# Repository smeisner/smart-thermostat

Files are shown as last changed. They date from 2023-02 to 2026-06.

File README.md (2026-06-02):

# Smart Thermostat

The idea of this project is to create a truly smart thermostat.
Main features are:

* Can be integrated into a home automation system (such as Home Assistant)
* Cloud connection not required
* WiFi connected
* Initial setup (e.g., WiFi credentials) configured via touch screen interface
* Will act similarly to a person's preferences when it comes to HVAC. For example:
    * the temperature set should be dependent upon local forecast
    * If the outside temp is close to the set thermostat temp, suggest opening a window
    * Detect if a window or door is open and disable the heat/AC
* Use Matter protocol over WiFi (thermostat V2)
* Provide local web site to control/configure thermostat
* Allow ssh login
* Provide diagnostic logging (rsyslog as well?)
* Detect degradation of temp rise/fall to identify clogged filter or service required
* Employ remote temp sensors to balance temp within home
* Detect lower air quality to suggest opening a window (and disable HVAC)
* No mechanical buttons - soft buttons on the TouchScreen only ... except maybe a master reset if things go wrong!

Basic layout of thermostat:

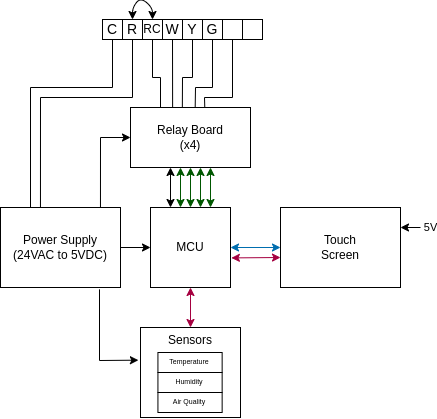
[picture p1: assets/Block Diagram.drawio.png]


# December 18, 2023 Changes to MQTT and addition of telnet support

Version 0.7.2 adds support for telnet and soft backlight bring up (more on that later). It also fixes a handful of bugs and reliability (especially around MQTT) has been dramatically increased.

Prior to this release, the backlight would come on immediately with "full brightness" (depending on the ambient light level). Now, the logic has been updated to bring the backlight up slowly to match the current room light level. Also the backlight will continue to match the detected light, so if you turn the room light on, it will match.

Auto reconnect in the ESP MQTT module has been enabled. This eliminates the responsibility for smart-thermostat to re-establish an MQTT connection if it is lost. Trying to do this manually led to race conditions and some incorrect logic assumptions. Now the built-in module (from Esspressif) handles it ... and it is incredibly reliable!

Telnet support has been added! There is no credential checking mechanism, but this is not a high security device. It could be added later by a contributor if wanted. Via telnet, a user can reconfigure the stat, monitoring the logging output, reboot and check on stats & error counts.

# October 4, 2023 addition of Matter support

Getting started: https://docs.espressif.com/projects/esp-matter/en/latest/esp32/developing.html

Matter support is delayed until the SDK can be added as a library to PlatformIO. Currently, the actions required to create a dev environment is too extreme.

# September 8, 2023 update - V0.6

The thermostat app code is now 100% ESP-IDF based. All dependencies on the Arduino framework have been removed. This provides for much better control of the code and better integration with the upcoming Matter implementation.

FYI: There are some libraries being used that have some compile-time errors. These are currently being worked with the maintainers. See PR comments.

FYI #2: Many details have changed with today's commit (such as the partition scheme). It is best to clear out old builds and be sure everything (ESP-IDF and libraries) are up-to-date. Details in the platformio.ini file.

# May 2023 update - V0.2

Great progress! The processor has been selected, the ESP-32 and the user interface is (albeit crude) created! To generate the user interface elements and menuing system, [SquareLine Studio](https://squareline.io/) was used. This integrates with the graphics library used; [LVGL](https://lvgl.io/).

## Operating environment

FreeRTOS will be the OS. Tasks are created to drive the user interface, the state machine, the web server and reading of the sensors. The state machine will make up the primary task that runs on a continuous, low-priority loop. The user interface task, which drives the TFT is the highest priority. All other tasks will have higher priorities.

The code is currently exceeding the usual partitioning table, so the large_app partition scheme was used. OTA update has not been tried since switching to this partition scheme, but it may now be broken. Later with an ESP32 chip with a larger FLASH should be able to handle the code and perform OTA updates.

## MCU

The processor of choice is the ESP32 with 4MB FLASH.

The choice to use an Espressif MCU was made since it is cheaper, smaller and more simple to integrate into the circuit. It also provides enough GPIO pins to control everything.

Eventually, the ESP32-C6 will be used as it has support for [802.15.4 (Zigbee / Thread)](https://en.wikipedia.org/wiki/IEEE_802.15.4). But it does not have enough GPIO pins, so a multiplexer must be added to the PCB. Alternatively, WiFi plus Matter could be used and skip Zigbee and Thread. This is still under investigation.

Built onto the PCB is a SWD interface allowing GDB debugging, as well as loading firmware. 

Currently, build output shows:

```
Processing esp32dev (platform: espressif32; board: esp32dev; framework: arduino)
---------------------------------------------------------------------------------------------------------------------------------------------------------------------------------
Verbose mode can be enabled via `-v, --verbose` option
CONFIGURATION: https://docs.platformio.org/page/boards/espressif32/esp32dev.html
PLATFORM: Espressif 32 (6.3.0) > Espressif ESP32 Dev Module
HARDWARE: ESP32 240MHz, 320KB RAM, 4MB Flash
DEBUG: Current (esp-prog) External (cmsis-dap, esp-bridge, esp-prog, iot-bus-jtag, jlink, minimodule, olimex-arm-usb-ocd, olimex-arm-usb-ocd-h, olimex-arm-usb-tiny-h, olimex-jtag-tiny, tumpa)
PACKAGES: 
 - framework-arduinoespressif32 @ 3.20009.0 (2.0.9) 
 - tool-esptoolpy @ 1.40501.0 (4.5.1) 
 - tool-mkfatfs @ 2.0.1 
 - tool-mklittlefs @ 1.203.210628 (2.3) 
 - tool-mkspiffs @ 2.230.0 (2.30) 
 - toolchain-xtensa-esp32 @ 8.4.0+2021r2-patch5
LDF: Library Dependency Finder -> https://bit.ly/configure-pio-ldf
LDF Modes: Finder ~ deep, Compatibility ~ soft
Found 42 compatible libraries
Scanning dependencies...
Dependency Graph
|-- LovyanGFX @ 1.1.6
|-- Adafruit AHTX0 @ 2.0.3
|-- Smoothed @ 1.2.0
|-- micro-timezonedb @ 1.0.2
|-- lvgl @ 8.3.7
|-- Preferences @ 2.0.0
|-- ESPmDNS @ 2.0.0
|-- Update @ 2.0.0
|-- WebServer @ 2.0.0
|-- WiFi @ 2.0.0
Building in release mode
Retrieving maximum program size .pio/build/esp32dev/firmware.elf
Checking size .pio/build/esp32dev/firmware.elf
Advanced Memory Usage is available via "PlatformIO Home > Project Inspect"
RAM:   [===       ]  33.1% (used 108372 bytes from 327680 bytes)
Flash: [=====     ]  45.9% (used 1445209 bytes from 3145728 bytes)
Configuring upload protocol...
AVAILABLE: cmsis-dap, esp-bridge, esp-prog, espota, esptool, iot-bus-jtag, jlink, minimodule, olimex-arm-usb-ocd, olimex-arm-usb-ocd-h, olimex-arm-usb-tiny-h, olimex-jtag-tiny, tumpa
CURRENT: upload_protocol = esptool
Looking for upload port...
Using manually specified: /dev/ttyUSB1
Uploading .pio/build/esp32dev/firmware.bin
esptool.py v4.5.1
Serial port /dev/ttyUSB1
Connecting.....
Chip is ESP32-D0WD-V3 (revision v3.0)
Features: WiFi, BT, Dual Core, 240MHz, VRef calibration in efuse, Coding Scheme None
Crystal is 40MHz
MAC: 78:21:84:e2:28:1c
Uploading stub...
Running stub...
Stub running...
Changing baud rate to 921600
Changed.
Configuring flash size...
Flash will be erased from 0x00001000 to 0x00005fff...
Flash will be erased from 0x00008000 to 0x00008fff...
Flash will be erased from 0x0000e000 to 0x0000ffff...
etc...
```

## Touch screen

The TFT display chosen is the [MSP3218](http://www.lcdwiki.com/3.2inch_SPI_Module_ILI9341_SKU:MSP3218) with the ILI9341 TFT driver and the XPT2046 touch controller. LVGL supports this display nicely (see lvgl_conf.h). The 3.2" screen is a bit tight for all menus and controls, but with a stylus, it is fine ... might be tough with a finger.

SquareLine Studio designed screens:<br>
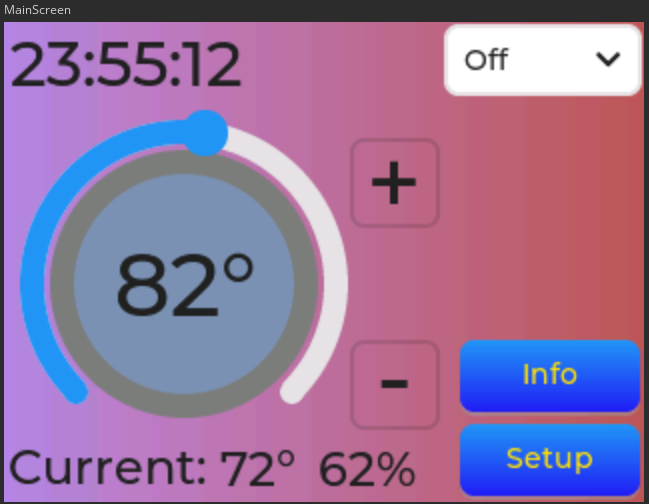
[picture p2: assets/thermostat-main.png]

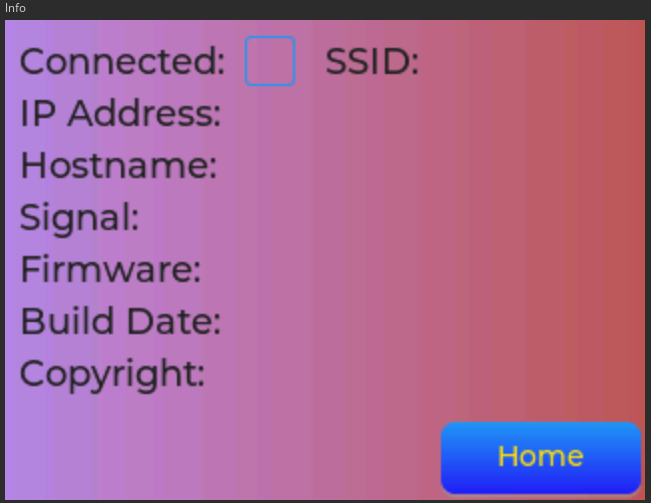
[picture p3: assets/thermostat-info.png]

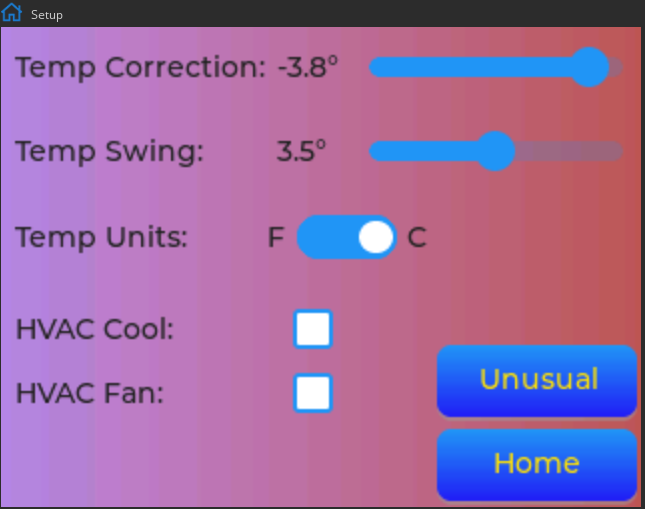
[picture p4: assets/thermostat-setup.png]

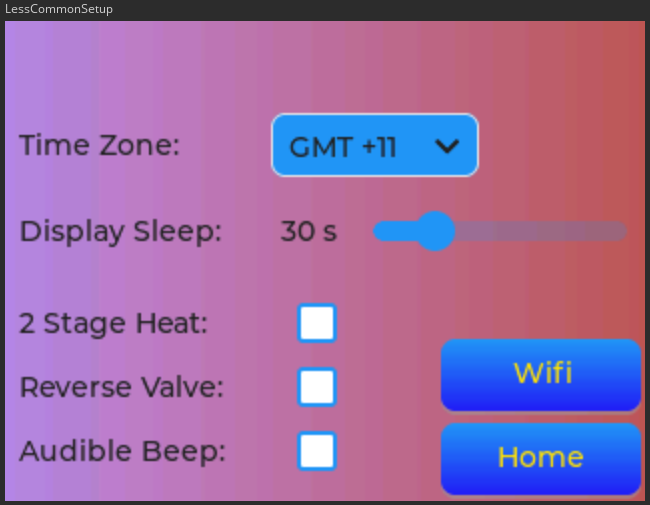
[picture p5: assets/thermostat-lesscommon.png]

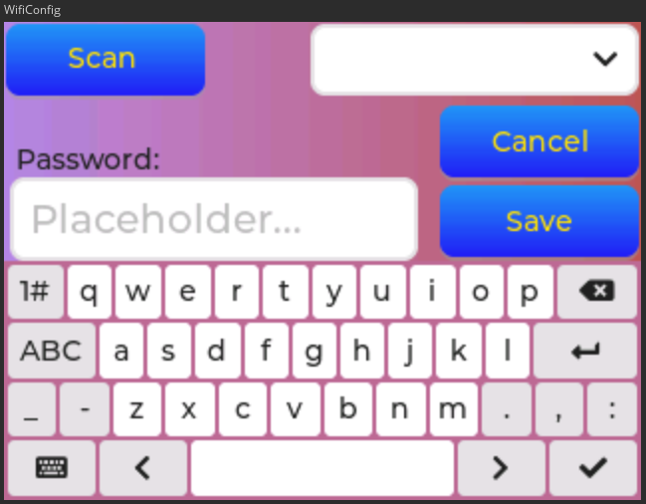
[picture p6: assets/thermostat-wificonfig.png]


## Power Supply

Built into the PCB is a power supply capable of providing stable 5V DC for the processor and sensors. An LM2576HVT-5 will be used to allow for 24V in and still remain stable regulating the power.

[LM2576HVT Datasheet](https://www.ti.com/general/docs/suppproductinfo.tsp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)

A low dropout voltage regulator is incorporated into the PCB to regulate the 5V to 3v3. [AMS1117 Datasheet](http://www.advanced-monolithic.com/pdf/ds1117.pdf)

## Sensors

Other than an onboard Temp/Humidity/Air quality sensor setup, there can also be remote sensors (maybe connected via MQTT or proprietary ethernet protocol?) that will provide data to make various decisions. These could be inside the home, outside or even from online sources (such as local weather sites).

To measure indoor temp & humidity, the [Aosong AHT20](http://www.aosong.com/userfiles/files/media/Data%20Sheet%20AHT20.pdf) is being used. More manufacturer information can be found [HERE](http://www.aosong.com/en/products-32.html).

A light sensor (LDR) is currently incoporated into the PCB (as a voltage divider) and is being measured for ambient light. It will be used to determine brightness of the TFT display when it is woken.

Motion sensing is being done with the Hi-Link LD2410 uWave sensor. These are available on [Amazon](https://www.amazon.com/Microwave-Radar-Sensor-Module-LD2410-24GHz-ISM-Band-Human-Presence-Motion-Sensing-Module-Non-Contact-Monitoring-Detector-Support-GPIO/dp/B0BP6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) and [AliExpress](https://m.aliexpress.com/item/1005004351593073.html).

* LD2410 documentation: https://drive.google.com/drive/folders/1p4dhbEJA3YubyIjIIC7wwVsSo8x29Fq-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
* Example use in another poject: https://github.com/LoopOnCode/UnitySensor
* You can purchase a Unity Sensor at: https://loopon.tech/products/unity-sensor

## Possibilities

#### Integrate SMS/chat ability

This can be used to notify user of events/alerts. Could also be Slack or other notifications. An onboard annunciator (like a speaker) feels wrong.

#### Use super capacitor to maintain power during power outage

This would maintain power during brief power outages

***

V1 task list:

* [x] Build 24VAC to 5VDC power supply with minimal ripple (< 2%)
* [x] Decide on MCU/SBC
* [x] Determine sensors to be used (temp, humidity, air quality)
* [x] Develop V1 of host app (to get basic thermostat functionality)
* [x] Generate schematic & PCB
* [x] Generate PCB BOM (compatible with JLCPCB parts list)
* [x] Have PCB manufactured (JLCPCB)
* [x] Add OTA update ability (via web page)

V2 task list:

* [x] Design device web page; crude but done
* [x] Design 3D printed case (Polycase may be good supplier or JLCPCB)
* [ ] Implement Matter
* [ ] Develop Home Assistant integration (maybe via Matter?)
* [x] Add MQTT/HA communications (publish and subscriber support)

Maybe:

* [ ] Add air quality monitoring (to PCB and app)

General to-do:

* [ ] Measure current draw of entire thermostat, TFT LED backlight on & off
* [ ] Measure current draw with no TFT display attached
* [ ] Measure voltage ripple while under load
* [x] Redesign PCB to incoporate ESP chip and tighten up layout
* [x] Add serial output pins to connect serial terminal to catch print statements

## Specs...
 
#### FreeRTOS Elements:
 
* Interrupt: Touch
* When: User touches display; Asserts line LO
<br>

* Interrupt: Motion
* When: LD2410 senses motion; asserts line HI
<br>

* Task: aht
* Freq: 10 secs
* Purpose: update temp & humidity
<br/>

* Task: touch
* Freq: int (triggered indirectly via TFT touch int)
* Purpose:
  - Update last touch point
  - Play audible beep
<br>

* Task: motion
* Freq: int (triggered directly via motion int)
* Purpose: update last motion detected timestamp
<br/>

* Task: state-machine
* Freq: 1 sec
* Purpose:
  - Pump state machine
  - Using temp & humidity, motion, last touch pt,
  - Call routines to navigate menus (options / settings)
  - Adjust display brightness (when on) based on LDR
  - Turn off display with no motion

#### States:

* Init (start)
* Idle
* Fan only
* Heat
* Cool
* Error

#### To be added:

* [x] WiFi
* [x] Web server
* [ ] Matter over WiFi
* [x] Telnet
* [x] OTA updates
* [ ] Add air quality monitoring device -- Maybe a future feature

#### Parameters set by user:

* WiFi credentials
* Location (zip code) for outdoor temp - or URI for local/private temp sensor
* Home Assistant FQDN / IP
* Temp swing
* Max / min temp (when to alert user)
* email list / SMS for notifications
* c / f
* reversing valve (for a heat pump)
* auto changeover (A/C to/from Heat)

#### Calculated params:

* Average temp change rate vs temp differential (inside / outside temps)
    * When value exceeded (based on HVAC mode), ask if window/door is open
* Average temp change rate
    * Detects when filter / furnace needs servicing
    * Used to calculate time to temp

#### Analyze core dump core:

Be sure ESP tools are installed:
```~/.platformio/packages/framework-espidf/install.sh```
<br><br>
Then run export:
```source ~/.platformio/packages/framework-espidf/export.sh```
<br><br>
Then run the ```esp-coredump``` utility to analyze a core dump file. It will be stored on the SD card in the event of a crash.
<br><br>
* Example;
  ```esp-coredump info_corefile --rom-elf ~/.espressif/tools/esp-rom-elfs/20241011/esp32s3_rev0_rom.elf -c ~/COREDUMP.BIN ~/projects/smart-thermostat/app/.pio/build/esp32s3/firmware.elf```
<br><br>
Another possible location for chip ELF files:
```~/.platformio/tools/tool-esp-rom-elfs/```

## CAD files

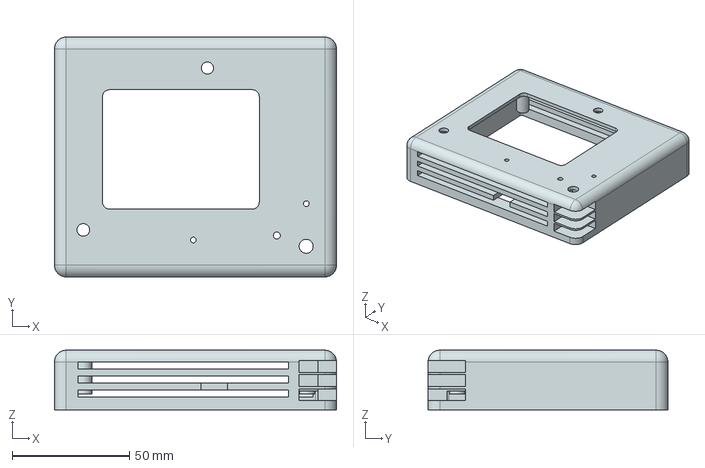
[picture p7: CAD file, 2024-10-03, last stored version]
pcb/3d/thermo-housing-front.stp
120.5 x 102.5 x 25.5 mm

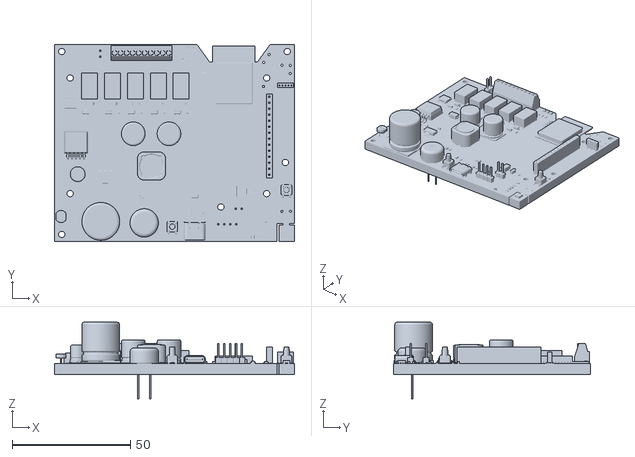
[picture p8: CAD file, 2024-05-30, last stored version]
pcb/FabConvert.com_thermostat v0.6.0.stl
101.5 x 83.4 x 32.5

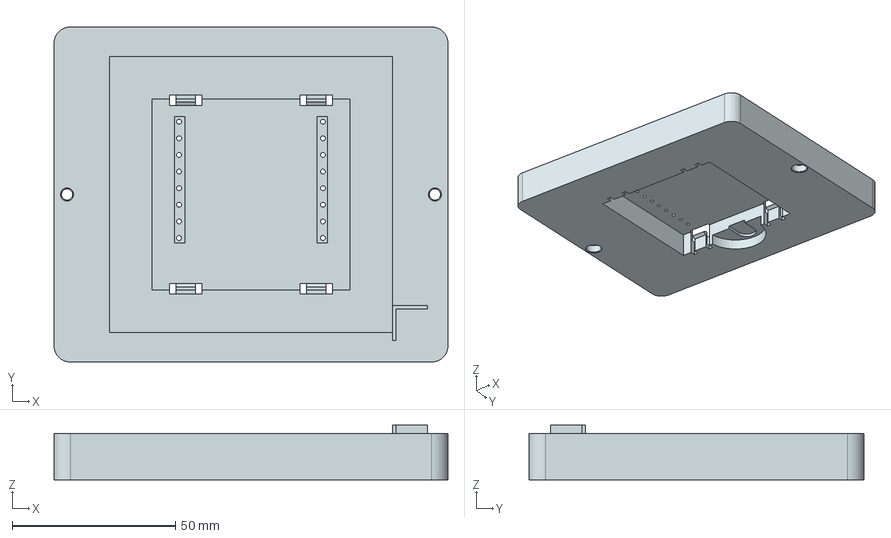
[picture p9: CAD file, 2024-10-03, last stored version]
pcb/3d/thermo-housing-back.stp
120.5 x 102.5 x 16.7 mm

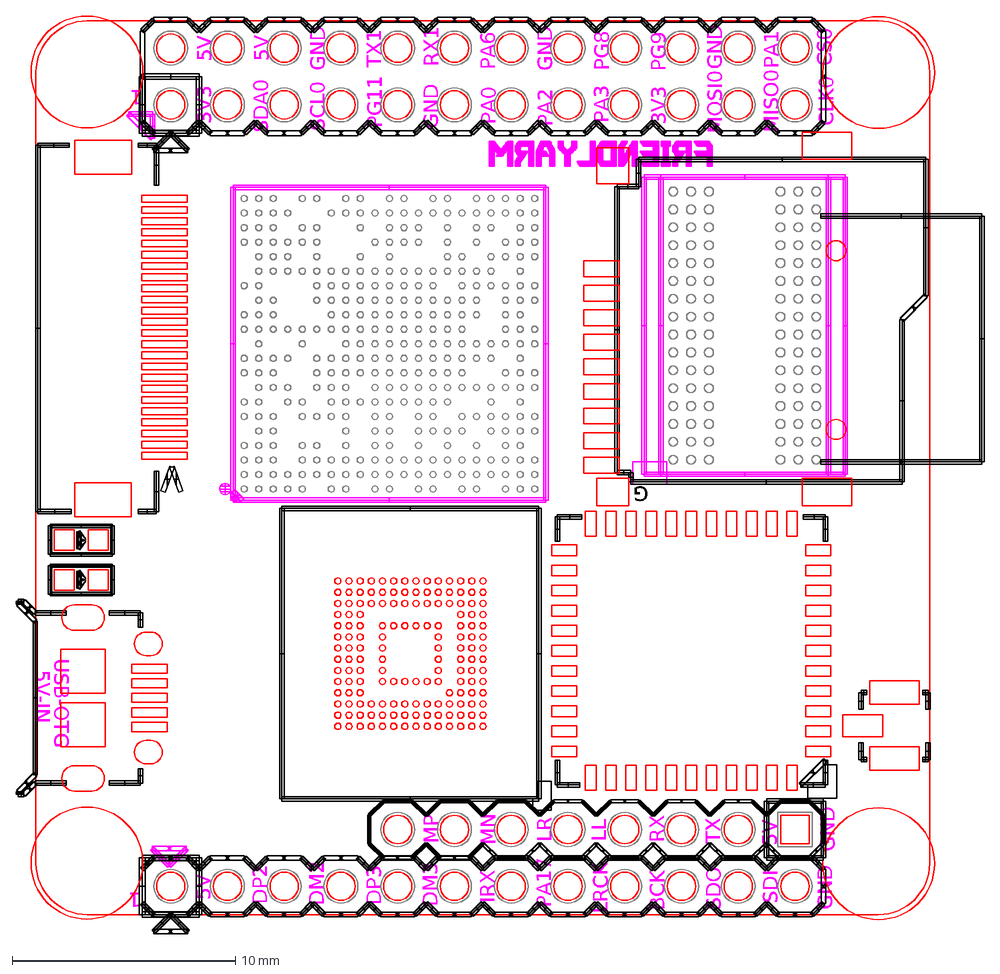
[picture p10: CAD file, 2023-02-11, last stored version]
pcb/NanoPi_NEO_Air-V1.1-1708.dxf
CS0
PA1
GND
PG9
PG8
PA6
RX1
TX1
5V
CLK0
MISO0
MOSI0
3V3
PA3
PA2
PA0
PG11
SCL0
SDA0
RX
LR
LL
TX
SDI
SDO
BCK
LRCK
PA17
MN
IRX
MP
DM3
DP3
DM2
DP2
USB-OTG
5V-IN
1
G

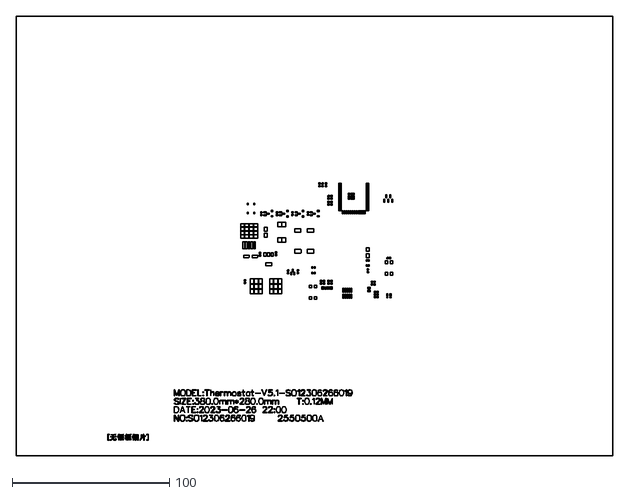
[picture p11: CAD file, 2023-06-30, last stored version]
pcb/stencil-v.0.5.1/SO12306266019.dxf
380.0 x 280.0

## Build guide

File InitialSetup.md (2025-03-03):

Upon first power up, follow these directions to setup wifi, set the device name and connect to MQTT:

First set up WIFI:
  1. From main screen, tap SETUP
  2. Tap the MORE button
  3. Then tap WIFI
  4. And finally perform a scan. After the scan completes, configure the SSID and password.
  5. Upon tapping SAVE, the thermostat should restart.

After the WIFI is connected (designated by Blue wifi icon on the home screen), perform the following:
  1. Tap SETUP
  2. MORE
  3. NAME
  4. In the text box, enter the Friendly Name to be used by Home Assistant. This name can include spaces.
  5. Tap SAVE
 
Now set up the MQTT connection:
  1. Tap SETUP
  2. MQTT
  3. Configure MQTT settings including broker, username and passowrd. Note: Port 1883 is assumed.

Once you return to the main screeen, go back into setup:
  1. Tap SETUP
  2. Check the box next to MQTT Enable
  3. Tap SAVE

NOTE: Using the telnet console, you can use the `config` command to go thru all of the configuration parameters, including setting the MQTT port. So it can be changed using this method.

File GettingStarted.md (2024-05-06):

# Getting Started

> [!NOTE]
> These steps are not fully verified or validated on every release yet or Linux distribution. Please add any modifications to them as needed.
>
> The instructions here preseted were tested on Debian 11 (Bullseye) and 12 (Bookworm), and Fedora 39.

## Release Notes

* NB #1: The v0.5.2 prototype boards have an odd connectivity issue with the USB ports. If you see 'oddness', flip the cable around and try that. It should work since all prototypes are tested before leaving my workbench.

* NB #2: There was an error on the v0.5.2 proto; the top right corner has 3 test points; GND, 5V and 3V3. I misconfigured the net connection for the 3v3 and it ended up not being connected. So don't use it to test...it's not connected.

* NB #3: If the board has been powered off for a bit, it starts up in boot mode when power is applied. Therefore, the reset button must be pushed. I am guessing this is a power-up problem...if anyone can suggest a PCB change, I will include it in the next run!

## Steps to build environment:

### Of course, update the system first:

<details>
<summary>Debian</summary>

`sudo apt update --allow-releaseinfo-change && sudo apt upgrade`
</details>

<details>
<summary>Fedora</summary>

`sudo dnf upgrade --refresh`
</details>

### Install the prerequisite packages

<details>
<summary>Debian</summary>

`sudo apt install git curl wget python3-pip python3-venv apt-transport-https gpg`
</details>

<details>
<summary>Fedora</summary>

On Fedora, python3 already bundles venv module by default<br>
`sudo dnf install git curl wget python3-pip gnupg`
</details>

### Build the dev environment:

#### Install Visual Studio Code

The following info was mostly got from https://code.visualstudio.com/docs/setup/linux

<details>
<summary>Debian</summary>

```
$ wget -qO- https://packages.microsoft.com/keys/microsoft.asc | gpg --dearmor > packages.microsoft.gpg
$ sudo install -D -o root -g root -m 644 packages.microsoft.gpg /etc/apt/keyrings/packages.microsoft.gpg
$ sudo sh -c 'echo "deb [arch=amd64,arm64,armhf signed-by=/etc/apt/keyrings/packages.microsoft.gpg] https://packages.microsoft.com/repos/code stable main" > /etc/apt/sources.list.d/vscode.list'
$ rm -f packages.microsoft.gpg
```

Add the VS Code repository to the cache:

`sudo apt update`

The above will add the repository key locally. Next we need to install the VS Code package itself:

`sudo apt install code`
</details>

<details>
<summary>Fedora</summary>

```
$ sudo rpm --import https://packages.microsoft.com/keys/microsoft.asc
$ echo -e "[code]\nname=Visual Studio Code\nbaseurl=https://packages.microsoft.com/yumrepos/vscode\nenabled=1\ngpgcheck=1\ngpgkey=https://packages.microsoft.com/keys/microsoft.asc" | sudo tee /etc/yum.repos.d/vscode.repo > /dev/null
```

Add the VS Code repository to the cache:

`sudo dnf update`

The above will add the repository key locally. Next we need to install the VS Code package itself:

`sudo dnf install code`
</details>

#### Install PlatformIO:<br>

```
$ curl -fsSL -o get-platformio.py https://raw.githubusercontent.com/platformio/platformio-core-installer/master/get-platformio.py`
$ python3 get-platformio.py
```

Add PlatformIO tools to the path:<br>

`echo "export PATH=\$PATH:/home/$USER/.platformio/penv/bin" >> ~/.profile`

#### Install udev rules

This will allow for recognizing the ESP32 USB JTAG device correctly.<br>
Source: [PlatformIO doc for 99-platformio-udev.rules](https://docs.platformio.org/en/stable/core/installation/udev-rules.html)

```
$ curl -fsSL https://raw.githubusercontent.com/platformio/platformio-core/develop/platformio/assets/system/99-platformio-udev.rules | sudo tee /etc/udev/rules.d/99-platformio-udev.rules
$ sudo udevadm control --reload-rules
```

Add user to the proper groups:

```
$ sudo usermod -a -G dialout $USER
$ sudo groupadd plugdev
$ sudo usermod -a -G plugdev $USER
```

NB: You must logout and back in again for this to take effect!! Otherwise, you will fail to write firmware images to the device.

#### Clone the thermostat repo

`git clone https://github.com/smeisner/smart-thermostat`

In the cloned repo, go into the 'app' folder and open the VS Code workspace smart-thermostat.code-workspace. With the included `platformio.ini` and the board definition files, you should be able to compile and flash to an ESP32-S3:

```
code smart-thermostat.code-workspace
```

If the above fails to launch VSCode, go to the system menu and select Visual Studio Code under Development. Then File, Open Workspace from File and navigate to the `smart-thermostat.code-workspace` file in the `app` folder.

In VS Code install the PlatformIO IDE extension (you should be prompted to add it). This will lead to installing many packages the first time. Any package needed by PlatformIO and the project will be installed. Once you see `Project has been successfully updated!`, all extra packages have been installed.

> [!CAUTION]
> A problem with ESP SDK/IDF has been discovered, causing build problems.
>
> In the file `esp_idf_version.h`, at `~/.platformio/packages/framework-espidf/components/esp_common/include/`, redefine the following macros, at the top of the module, to the values:
>
> ```c
> /** Major version number (X.x.x) */
> #define ESP_IDF_VERSION_MAJOR 6
> /** Minor version number (x.X.x) */
> #define ESP_IDF_VERSION_MINOR 6
> /** Patch version number (x.x.X) */
> #define ESP_IDF_VERSION_PATCH 0
> ```
>
> The default setup has the wrong IDF version (5.2.1), causing a number of yellow-colored warnings during build phase and a final build failure.
>
> Most of the warnings are: `warning: compound assignment with 'volatile'-qualified left operand is deprecated`
> that exist in the graphics library. They are warnings that can be ignored for now, **but they have been reported and hopefully addressed soon**.

Finally, plug in an ESP32-S3 based thermostat and try a build and flash the firmware via VSCode / PlatformIO!!

## Hints for setup & install

* Set up git properly to do pulls & commits
```
$ git config --global user.name "John Doe"
$ git config --global user.email johndoe@example.com
```
* Be sure sym link for python invokes python3 (I am using 3.9). Check "`which python`".

Notes:
a. Any PSRAM will be disabled. This is due to a pin conflicts on the MCU.
b. At least 8MB is required on the ESP32-S3 SOC. Adjust the `board\_build.partitions` in the `platformio.ini` as necessary.

### Components / Libraries used

***

**LovyanGFX** - Graphics driver for the MSP3218 TFT display and touch screen<br>
**lvgl** - Menuing system layered on top of LovyanGFX to generate screens and menus<br>
**micro-timezonedb** - Timezone database support to configure any timezone setting<br>
**Smoothed** - Automatically average values over a sample period<br>
**DFRobot_AHT20** - Class library to support the AHT20 sensor (much simpler and reliable than Adafruit's)<br>
**SquareLine Studio** - Design and develop the lvgl menuing system & screens.

### Debugging / flashing

***

The board includes a SWD port, but so far using the built in USB controller in the S3 has worked fine. This is also true for flashing new code over the USB port. The device will show up on the USB bus usually as `/dev/ttyACM0` which is the JTAG interface of the ESP32.

The following was removed. Leaving here as it may be reimplemented at some point:
```
There is also a 4 pin UART port on the board. This is used for serial comms. All serial.print statements end up here, as well as system debug information. In the state machine loop, the USB port is checked for input (as in the user typing on the serial console). Only a few commands are supported right now:
reset
scan
temp
The method implemented is very crude, so be careful!

`/dev/ttyUSBx` is the UART
`/dev/ttyACMx` is the ESP32
```

### Learning the source code

***

Start with the `main.cpp` file to understand the flow of the code. It is using FreeRTOS...but OS functions are used modestly, so it may not be obvious quickly. The `state_machine.cpp` module is the main loop of the thermostat (makes HVAC decisions and network retries). Other modules are fairly obvious.

Each module does have a brief description in the header.

`matter.cpp` is not yet being compiled as the SDK is not part of the environment yet.

### Resources/Links:

***

Install VS Code

* Download .deb file
    `wget https://code.visualstudio.com/sha/download?build=stable&os=linux-deb-x64`
    `sudo apt install ./code_1.79.0-1686149120_amd64.deb`

Install PlatformIO

* [https://platformio.org/install](https://platformio.org/install)
* Install as an extension inside Visual Studio Code
* Currently installed: PlatformIO IDE v3.2.0

Access Thermostat web interface

* [http://thermostat.local/](http://thermostat.local/)

ESP32 Arduino Matter port

* [https://github.com/Yacubane/esp32-arduino-matter](https://github.com/Yacubane/esp32-arduino-matter)
* [Announcement] [https://www.reddit.com/r/esp32/comments/yfq5sy/i_have_created_matter_library_for_esp32_running/](https://www.reddit.com/r/esp32/comments/yfq5sy/i_have_created_matter_library_for_esp32_running/)
* Download zip: `https://github.com/Yacubane/esp32-arduino-matter/releases/download/v1.0.0-beta.5/esp32-arduino-matter.zip`
    `cd smart-thermostat/app/lib`
    `gunzip "~/esp32-arduino-matter.zip"`

SquareLine Studio

* [https://squareline.io/](https://squareline.io/)

DFRobot AHT20 library

* [https://github.com/DFRobot/DFRobot_AHT20](https://github.com/DFRobot/DFRobot_AHT20)

LD2410 uWave Human Presence sensor

* [https://github.com/ncmreynolds/ld2410](https://github.com/ncmreynolds/ld2410)

PlatformIO documentation

* [https://docs.platformio.org/en/stable/what-is-platformio.html](https://docs.platformio.org/en/stable/what-is-platformio.html)

NTP Support library

* [https://mischianti.org/2020/08/08/network-time-protocol-ntp-timezone-and-daylight-saving-time-dst-with-esp8266-esp32-or-arduino/](https://mischianti.org/2020/08/08/network-time-protocol-ntp-timezone-and-daylight-saving-time-dst-with-esp8266-esp32-or-arduino/)

Arduino ESP32 doc

* [https://docs.espressif.com/\_/downloads/arduino-esp32/en/latest/pdf/](https://docs.espressif.com/_/downloads/arduino-esp32/en/latest/pdf/)

#### FreeRTOS

***

FreeRTOS and Task Priorities

* [https://www.freertos.org/RTOS-task-priority.html](https://www.freertos.org/RTOS-task-priority.html)

Amazon FreeRTOS User Guide

* [https://thingspace.verizon.com/content/dam/thingspace-portal/files/pdf/CloudConectors_Amazon_freertos-ug.pdf](https://thingspace.verizon.com/content/dam/thingspace-portal/files/pdf/CloudConectors_Amazon_freertos-ug.pdf)

Multitasking on ESP32 with Arduino and FreeRTOS

* [https://savjee.be/blog/multitasking-esp32-arduino-freertos/](https://savjee.be/blog/multitasking-esp32-arduino-freertos/)

Implement Freertos With Arduino Ide On Esp32

* [https://www.electromaker.io/project/view/implement-freertos-with-arduino-ide-on-esp32-1](https://www.electromaker.io/project/view/implement-freertos-with-arduino-ide-on-esp32-1)

ESP32 Interrupts and Timers with PIR Sensor using Arduino IDE

* [https://microcontrollerslab.com/esp32-interrupts-timers-pir-sensor-arduino-ide/](https://microcontrollerslab.com/esp32-interrupts-timers-pir-sensor-arduino-ide/)

#### Misc Hardware Info

***

ESP32 Espressif Hardware page

* [https://www.espressif.com/en/products/modules](https://www.espressif.com/en/products/modules)
* [https://www.espressif.com/en/products/socs/esp32-s3](https://www.espressif.com/en/products/socs/esp32-s3)

ESP32 device with thread (matter) support?

* [https://www.reddit.com/r/esp32/comments/1079h3a/esp32_device_with_thread_matter_support/](https://www.reddit.com/r/esp32/comments/1079h3a/esp32_device_with_thread_matter_support/)

Wifi management tricks

* [https://randomnerdtutorials.com/esp32-useful-wi-fi-functions-arduino/](https://randomnerdtutorials.com/esp32-useful-wi-fi-functions-arduino/)

Wifi connect using lvgl

* [https://github.com/xpress-embedo/ESP32/blob/master/ConnectToWiFi/src/main.cpp](https://github.com/xpress-embedo/ESP32/blob/master/ConnectToWiFi/src/main.cpp)
* [https://www.youtube.com/watch?v=X-Xv36ZO460](https://www.youtube.com/watch?v=X-Xv36ZO460)
* [https://github.com/pjaos/mgos_esp32_littlevgl_wifi_setup/blob/master/src/setup_wifi/setup_wifi_gui.c](https://github.com/pjaos/mgos_esp32_littlevgl_wifi_setup/blob/master/src/setup_wifi/setup_wifi_gui.c)

Article on PSRAM

* [https://thingpulse.com/esp32-how-to-use-psram/](https://thingpulse.com/esp32-how-to-use-psram/)

Touchscreen Controller (XPT2046)

* [https://github.com/PaulStoffregen/XPT2046_Touchscreen](https://github.com/PaulStoffregen/XPT2046_Touchscreen)

Switching Regulator Noise Reduction with an LC Filter

* [https://www.analog.com/media/en/technical-documentation/tech-articles/switching-regulator-noise-reduction-with-an-lc-filter.pdf](https://www.analog.com/media/en/technical-documentation/tech-articles/switching-regulator-noise-reduction-with-an-lc-filter.pdf)

I2C Scanner

* [https://learn.adafruit.com/adafruit-esp32-s3-feather/i2c-scan-test](https://learn.adafruit.com/adafruit-esp32-s3-feather/i2c-scan-test)

RCWL-0516 Range (Historical as this sensor is no longer planned for fab)

* [https://github.com/jdesbonnet/RCWL-0516/issues/11#issuecomment-771810294](https://github.com/jdesbonnet/RCWL-0516/issues/11#issuecomment-771810294)
* [https://github.com/jdesbonnet/RCWL-0516/issues/22](https://github.com/jdesbonnet/RCWL-0516/issues/22)

#### ESP32-S3 reference designs

***

* [https://learn.adafruit.com/assets/110822](https://learn.adafruit.com/assets/110822)
* [https://easyeda.com/editor#id=d056f47be7564dccbc8593766bcbeab5](https://easyeda.com/editor#id=d056f47be7564dccbc8593766bcbeab5)
* [https://easyeda.com/editor#id=4c9a270201564f79a8d898b16cb32a4a|030d87584b3241f4acb42f6090e3f78e|ad3bd37529b84bd0b1b817e14244c56d|10bc426910154bc18a781dce0e926303|ff30c5c9faf3437b93b7cbbef5ea03e9](https://easyeda.com/editor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)
* [https://oshwlab.com/thecharge/esp-32-s3-wroom-1-board-redesign](https://oshwlab.com/thecharge/esp-32-s3-wroom-1-board-redesign)
* [https://www.reddit.com/r/PrintedCircuitBoard/comments/110phjq/repostpcb_review_an_iot_playground_board_based_on/](https://www.reddit.com/r/PrintedCircuitBoard/comments/110phjq/repostpcb_review_an_iot_playground_board_based_on/)

#### USB Port sourcing (for PCB fab)

***

* [https://www.lcsc.com/product-detail/USB-Connectors_G-Switch-GT-USB-7010ASV_C2988369.html](https://www.lcsc.com/product-detail/USB-Connectors_G-Switch-GT-USB-7010ASV_C2988369.html)
* [https://www.jae.com/en/topics/detail/id=92529](https://www.jae.com/en/topics/detail/id=92529)
* [https://www.mouser.com/ProductDetail/JAE-Electronics/DX07S016JA1R1500?qs=GBLSl2Akirucb2YMMGCxCQ%3D%3D](https://www.mouser.com/ProductDetail/JAE-Electronics/DX07S016JA1R1500?qs=GBLSl2Akirucb2YMMGCxCQ%3D%3D)

#### Google Sheets

***

* Sheet to determine GPIO pin usage
   * [https://docs.google.com/spreadsheets/d/10CfVb4AoQPJP5FjagokVNWyHDSV7czo9InDzF5tszXg/edit#gid=0](https://docs.google.com/spreadsheets/d/10CfVb4AoQPJP5FjagokVNWyHDSV7czo9InDzF5tszXg/edit#gid=0)
* BOM Analysis
   * [https://docs.google.com/spreadsheets/d/14w7VYzvXJafxjo8qtsvuFqKP_Zvz_vr7KMgLZYts2Cs/edit?pli=1#gid=310427562](https://docs.google.com/spreadsheets/d/14w7VYzvXJafxjo8qtsvuFqKP_Zvz_vr7KMgLZYts2Cs/edit?pli=1#gid=310427562)

## Sample output from build (using ProxMox, passing thru the ESP32 USB device)
```
*  Executing task in folder SmartThermostat: platformio run --target upload 

Processing esp32dev (platform: espressif32; board: esp32-s3-thermostat; framework: arduino)
----------------------------------------------------------------------------------------------------------------
Tool Manager: Installing platformio/tool-mkspiffs @ ~2.230.0
Downloading  [####################################]  100%
Unpacking  [####################################]  100%
Tool Manager: tool-mkspiffs@2.230.0 has been installed!
Tool Manager: Installing platformio/tool-mklittlefs @ ~1.203.0
Downloading  [####################################]  100%
Unpacking  [####################################]  100%
Tool Manager: tool-mklittlefs@1.203.210628 has been installed!
Tool Manager: Installing platformio/tool-mkfatfs @ ~2.0.0
Downloading  [####################################]  100%
Unpacking  [####################################]  100%
Tool Manager: tool-mkfatfs@2.0.1 has been installed!
Verbose mode can be enabled via `-v, --verbose` option
CONFIGURATION: https://docs.platformio.org/page/boards/espressif32/esp32-s3-thermostat.html
PLATFORM: Espressif 32 (6.2.0) > Espressif ESP32-S3-Thermostat (16 MB QD, No PSRAM)
HARDWARE: ESP32S3 240MHz, 320KB RAM, 16MB Flash
DEBUG: Current (esp-builtin) On-board (esp-builtin) External (cmsis-dap, esp-bridge, esp-prog, iot-bus-jtag, jlink, minimodule, olimex-arm-usb-ocd, olimex-arm-usb-ocd-h, olimex-arm-usb-tiny-h, olimex-jtag-tiny, tumpa)
PACKAGES: 
 - framework-arduinoespressif32 @ 3.20008.0 (2.0.8) 
 - tool-esptoolpy @ 1.40501.0 (4.5.1) 
 - tool-mkfatfs @ 2.0.1 
 - tool-mklittlefs @ 1.203.210628 (2.3) 
 - tool-mkspiffs @ 2.230.0 (2.30) 
 - toolchain-riscv32-esp @ 8.4.0+2021r2-patch5 
 - toolchain-xtensa-esp32s3 @ 8.4.0+2021r2-patch5
LDF: Library Dependency Finder -> https://bit.ly/configure-pio-ldf
LDF Modes: Finder ~ deep, Compatibility ~ soft
Found 37 compatible libraries
Scanning dependencies...
Dependency Graph
|-- LovyanGFX @ 1.1.7
|-- Smoothed @ 1.2.0
|-- micro-timezonedb @ 1.0.2
|-- lvgl @ 8.3.7
|-- Wire @ 2.0.0
|-- Preferences @ 2.0.0
|-- ESPmDNS @ 2.0.0
|-- Update @ 2.0.0
|-- WebServer @ 2.0.0
|-- WiFi @ 2.0.0
Building in release mode
Retrieving maximum program size .pio/build/esp32dev/firmware.elf
Checking size .pio/build/esp32dev/firmware.elf
Advanced Memory Usage is available via "PlatformIO Home > Project Inspect"
RAM:   [===       ]  33.4% (used 109528 bytes from 327680 bytes)
Flash: [====      ]  42.8% (used 1431745 bytes from 3342336 bytes)
Configuring upload protocol...
AVAILABLE: cmsis-dap, esp-bridge, esp-builtin, esp-prog, espota, esptool, iot-bus-jtag, jlink, minimodule, olimex-arm-usb-ocd, olimex-arm-usb-ocd-h, olimex-arm-usb-tiny-h, olimex-jtag-tiny, tumpa
CURRENT: upload_protocol = esptool
Looking for upload port...
Auto-detected: /dev/ttyACM0
Uploading .pio/build/esp32dev/firmware.bin
esptool.py v4.5.1
Serial port /dev/ttyACM0
Connecting...
Chip is ESP32-S3 (revision v0.1)
Features: WiFi, BLE
Crystal is 40MHz
MAC: f4:12:fa:ee:3f:e4
Uploading stub...
Running stub...
Stub running...
Changing baud rate to 921600
Changed.
Configuring flash size...
Flash will be erased from 0x00000000 to 0x00003fff...
Flash will be erased from 0x00008000 to 0x00008fff...
Flash will be erased from 0x0000e000 to 0x0000ffff...
Flash will be erased from 0x00010000 to 0x0016dfff...
Compressed 15040 bytes to 10333...
Writing at 0x00000000... (100 %)
Wrote 15040 bytes (10333 compressed) at 0x00000000 in 0.2 seconds (effective 498.7 kbit/s)...
Hash of data verified.
Compressed 3072 bytes to 146...
Writing at 0x00008000... (100 %)
Wrote 3072 bytes (146 compressed) at 0x00008000 in 0.0 seconds (effective 543.8 kbit/s)...
Hash of data verified.
Compressed 8192 bytes to 47...
Writing at 0x0000e000... (100 %)
Wrote 8192 bytes (47 compressed) at 0x0000e000 in 0.1 seconds (effective 737.3 kbit/s)...
Hash of data verified.
Compressed 1432112 bytes to 828286...
Writing at 0x00010000... (1 %)
Writing at 0x00018cb1... (3 %)
Writing at 0x00020829... (5 %)
Writing at 0x0002946b... (7 %)
Writing at 0x00032cc9... (9 %)
Writing at 0x0003fa80... (11 %)
Writing at 0x00050787... (13 %)
Writing at 0x000605a9... (15 %)
Writing at 0x00070969... (17 %)
Writing at 0x0007c4d1... (19 %)
Writing at 0x0008ab5a... (21 %)
Writing at 0x00093f36... (23 %)
Writing at 0x00099473... (25 %)
Writing at 0x0009ee0f... (27 %)
Writing at 0x000a445d... (29 %)
Writing at 0x000a9b47... (31 %)
Writing at 0x000aeb6f... (33 %)
Writing at 0x000b3e61... (35 %)
Writing at 0x000b8fb1... (37 %)
Writing at 0x000be0ab... (39 %)
Writing at 0x000c32ba... (41 %)
Writing at 0x000c8eae... (43 %)
Writing at 0x000ced8c... (45 %)
Writing at 0x000d4afd... (47 %)
Writing at 0x000da61a... (49 %)
Writing at 0x000dfca6... (50 %)
Writing at 0x000e56f9... (52 %)
Writing at 0x000ea6d0... (54 %)
Writing at 0x000ef6bb... (56 %)
Writing at 0x000f44b6... (58 %)
Writing at 0x000f9419... (60 %)
Writing at 0x000fe34e... (62 %)
Writing at 0x00103267... (64 %)
Writing at 0x001083ba... (66 %)
Writing at 0x0010d398... (68 %)
Writing at 0x00112d03... (70 %)
Writing at 0x00118394... (72 %)
Writing at 0x0011d177... (74 %)
Writing at 0x00122281... (76 %)
Writing at 0x00127165... (78 %)
Writing at 0x0012c6ad... (80 %)
Writing at 0x00131b31... (82 %)
Writing at 0x0013787c... (84 %)
Writing at 0x0013ce67... (86 %)
Writing at 0x001424a3... (88 %)
Writing at 0x0014a6b3... (90 %)
Writing at 0x00153576... (92 %)
Writing at 0x00158e7c... (94 %)
Writing at 0x0015f0e6... (96 %)
Writing at 0x00164997... (98 %)
Writing at 0x0016a73c... (100 %)
Wrote 1432112 bytes (828286 compressed) at 0x00010000 in 9.9 seconds (effective 1156.4 kbit/s)...
Hash of data verified.

Leaving...
Hard resetting via RTS pin...
========================================= [SUCCESS] Took 28.32 seconds =========================================
 *  Terminal will be reused by tasks, press any key to close it. 
```

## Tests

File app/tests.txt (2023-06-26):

Verify update over the air works
Motion detection operates
Voltage ripple minimal under load
Light detection operates corretly (display diming influenced correctly)
Waking display (via touch) from dim and from sleep work correctly
Validate HVAC mode change via touch
Validate HVAC mode change via web page
Validate temperature change via touch
Validate temperature change via web page
Validate all config menu items via touch

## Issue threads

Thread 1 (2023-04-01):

Motion sensor too sensitive

smeisner, 2023-04-01:
With the RCWL-0516 mounted upside down (looking at rear of board), it is constantly triggering for motion. This makes the sensor virtually useless.

smeisner, 2023-04-02:
On the reverse of the RCWL-0516, there is a spot for a R-GN 0603 SMD resistor. 82k seems to lower the range too much. 1M is supposed to be for ~5 meter range. But, this is with the RCWL-0516 mounted reverse.

Maybe a POT to adjust the range?

smeisner, 2023-05-25:
Investigating the use of the [LD2410](https://www.hlktech.net/index.php?id=988) uWave sensor instead

smeisner, 2023-06-26:
The LD2410 will be used from now on. The last boards included the uWave sensor and has been working flawlessly. Code will be added to program the sensor on start up via TX1/RX1

Closed 2023-06-26.

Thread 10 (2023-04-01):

Add support for Matter over wifi

smeisner, 2023-04-01:
After the ESP32-C6 MCU is incorporated, research how to enable Thread protocol to support Matter. This allows for integration into home automation systems.

Must be able to be enabled/disabled via user config on touchscreen.

smeisner, 2023-04-19:
Possibility to only use Matter over wifi as well and leave Thread out of the design.

The main motivation to incorporate Thread would be to create a Thread border router since the thermostat is constantly powered.

smeisner, 2023-06-26:
The following library will be used to implement Matter over wifi:
https://github.com/Yacubane/esp32-arduino-matter

smeisner, 2023-11-02:
Completed with merge https://github.com/smeisner/smart-thermostat/commit/b1bfc1dfeed0b9eb6768a07f68dbf599092f3d0c

smeisner, 2023-12-29:
This code is not operational yet, so re-opening issue. Once the code is compiled in and running, this can be closed.

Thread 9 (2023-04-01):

Zigbee

smeisner, 2023-04-01:
Once the onboard MCU is switched to the ESP32-C6 (which has Zigbee support), research must be done to figure out how to enable Zigbee on it. This will allow comms with home automation systems.

Must be able to be enabled/disabled via user config on touchscreen.

smeisner, 2023-04-14:
Waiting for ESP32-C6 or H2 as they support Zigbee

smeisner, 2023-06-26:
The decision to use the -S3 variant of the ESP32 has been finalized. This SOC does not provide a 802.15.4 radio, so Thread over Wifi will be implemented.

Closed 2023-06-26.

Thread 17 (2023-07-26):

Switch to ESP-IDF framework

smeisner, 2023-07-26:
To get rid of Arduino dependencies, we need to switch to the ESP-IDF framework. Most libraries are already ESP-IDF compliant. The problem (I believe) is with the DFRobot AHT20 library. It relies on the Arduino framework, specifically the I2C library.

smeisner, 2023-07-26:
Preferences library also needs to be researched and replaced or code modified to work with the lib

smeisner, 2023-09-08:
Preferences library has been removed

smeisner, 2023-09-08:
AHT20 library has been removed as well. The LD2410 lib is supported via a Stream class now included with the project.

smeisner, 2023-09-10:
Closed as of PR / merge https://github.com/smeisner/smart-thermostat/pull/20

Closed 2023-09-10.

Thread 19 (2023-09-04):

Temperature via matter

beckmx, 2023-09-04:
Hello there, I was looking at your code and was wondering if you managed to set the temperature into the matter protocol, I just noticed this part **local_temperature**, or do you have any clue on how to send the temperature via matter?

smeisner, 2023-09-04:
This PCB & code are almost ready for "V1", but it is not there quite yet. Actually on another branch I have been rewriting all of the code to NOT use the Arduino framework and only use ESP-IDF. Once I get that code committed, I will be returning to the Matter implementation.

As far as Matter, so far I have managed to get Matter up and running with the CHIP ESP component and have the server (HomeAssistant) recognize my thermostat. Doing just that was quite an exercise. The very next step is to allow HomeAssistant to control the mode and temp using Matter over wifi ...and to report back to HA the current states.

So, to answer your question, no, not yet.  :D I believe sending the temp back is done via a Matter callback, but I need to investigate further.

beckmx, 2023-09-06:
use this, i tried it and joined ur code with this, worked nicely https://github.com/aleksigold/esp-matter-temperature

Closed 2023-09-06.

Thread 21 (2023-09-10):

Save config settings to NVS

smeisner, 2023-09-10:
Whenever settings change, save them to the NV storage area. This can include:

- All fields of OperatingParameters struct
- Wifi creds
- Calibration data for touch screen (also need to restore this on startup)
- Historical data (such as reboot count)

smeisner, 2023-11-02:
Completed with merge https://github.com/smeisner/smart-thermostat/commit/b1bfc1dfeed0b9eb6768a07f68dbf599092f3d0c

Closed 2023-11-02.

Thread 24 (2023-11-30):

Motion & light level sensor data via MQTT

smeisner, 2023-11-30:
Report motion and light level back via MQTT. This will allow home automation systems to take action based on sensor data.

smeisner, 2024-01-21:
Fixed as of commit 8a14d1d.

Motion detection transmistted via MQTT, but not light level. If light level is desired, all the framework necessary is now present. Just ad on to motion sensor.

Closed 2024-01-21.

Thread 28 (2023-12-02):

Turn on fan pin with heat or cool

smeisner, 2023-12-02:
(G) Fan must be energized whenever (W) HEAT or (Y) COOL is asserted.

smeisner, 2023-12-02:
Many modern HAVAC systems do not require this, but older ones can very well require FAN when heat or cool is called for.

y9rabbito, 2023-12-02:
Can you specifically elaborate it and in which file i need to update the fan control signal G.

smeisner, 2023-12-02:
the relay pins are controlled in state_machine.cpp. In the main loop is where the decisions are made to turn on/off each relay...and LEDs, if appropriate.

y9rabbito, 2023-12-02:
@smeisner means this value gpio_set_level((gpio_num_t)LED_FAN_PIN, LOW); should be set to high on coolstate currenttemp > maxtemp

smeisner, 2023-12-02:
Yes, that will turn on/off the LED. I think you want to look for HVAC_FAN_PIN to control the relay. For heat, the red LED is turned on. For cool, the blue is turned on. If only the fan is turned on, the green LED is turned on. If the fan is turned on as part of cooling/heating, there is no need to turn on the LED.

y9rabbito, 2023-12-02:
Actually i have never read or know about HVAC system Im googling the topic and trying to understand the code.

smeisner, 2023-12-04:
This issue was addressed with e7d7b29dbfe0932cfff6a9a89d79f6e1776096d0.
Code has beenmerged.

Closed 2023-12-04.

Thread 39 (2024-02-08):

Crash during wifi reconnect

smeisner, 2024-02-08:
Crashed while wifi was dropping and connection reestablished:
```
[19761.20h.02m.32s.829] I (196938675) SENSORS: Temp: 75.1 (raw: 80.60 F)  Humidity: 34.0 (raw: 21.71)
[19761.20h.02m.32s.836] I (196938675) MQTT: {"Temperature":"75.06","Humidity":"34.02","Setpoint":74,"Mode":"heat","CurrMode":"idle"}
[19761.20h.02m.42s.918] I (196948765) SENSORS: Temp: 75.0 (raw: 80.57 F)  Humidity: 33.7 (raw: 20.84)
[19761.20h.02m.42s.926] I (196948765) MQTT: {"Temperature":"75.01","Humidity":"33.70","Setpoint":74,"Mode":"heat","CurrMode":"idle"}
[19761.20h.02m.53s.008] I (196958855) SENSORS: Temp: 75.0 (raw: 80.54 F)  Humidity: 33.4 (raw: 20.24)
[19761.20h.02m.53s.015] I (196958855) MQTT: {"Temperature":"74.96","Humidity":"33.36","Setpoint":74,"Mode":"heat","CurrMode":"idle"}
[19761.20h.03m.03s.099] I (196968945) SENSORS: Temp: 74.9 (raw: 80.47 F)  Humidity: 33.0 (raw: 19.91)
[19761.20h.03m.03s.106] I (196968945) MQTT: {"Temperature":"74.91","Humidity":"33.01","Setpoint":74,"Mode":"heat","CurrMode":"idle"}
[19761.20h.03m.13s.188] I (196979035) SENSORS: Temp: 74.9 (raw: 80.43 F)  Humidity: 32.7 (raw: 19.79)
[19761.20h.03m.13s.195] I (196979035) MQTT: {"Temperature":"74.87","Humidity":"32.69","Setpoint":74,"Mode":"heat","CurrMode":"idle"}
[19761.20h.03m.23s.278] I (196989125) SENSORS: Temp: 74.8 (raw: 80.39 F)  Humidity: 32.4 (raw: 19.33)
[19761.20h.03m.23s.285] I (196989125) MQTT: {"Temperature":"74.82","Humidity":"32.35","Setpoint":74,"Mode":"heat","CurrMode":"idle"}
[19761.20h.03m.24s.853] I (196990705) SENSORS: Current time: 15:03:24
[19761.20h.03m.33s.369] I (196999215) SENSORS: Temp: 74.8 (raw: 80.33 F)  Humidity: 32.0 (raw: 19.06)
[19761.20h.03m.33s.376] I (196999215) MQTT: {"Temperature":"74.77","Humidity":"32.02","Setpoint":74,"Mode":"heat","CurrMode":"idle"}
[19761.20h.03m.39s.383] I (197005235) wifi:bcn_timeout,ap_probe_send_start
[19761.20h.03m.41s.885] I (197007735) wifi:ap_probe_send over, resett wifi status to disassoc
[19761.20h.03m.41s.885] I (197007735) wifi:state: run -> init (c800)
[19761.20h.03m.41s.890] I (197007735) wifi:pm stop, total sleep time: 92468438 us / 130538481 us
[19761.20h.03m.41s.890]
[19761.20h.03m.41s.894] I (197007735) wifi:<ba-del>idx:0, tid:0
[19761.20h.03m.41s.901] I (197007745) wifi:new:<1,0>, old:<1,0>, ap:<255,255>, sta:<1,0>, prof:1
[19761.20h.03m.41s.907] I (197007755) telnet: Telnet session termination requested
[19761.20h.03m.41s.913] I (197007755) telnet: Starting new telnet service instance
[19761.20h.03m.41s.923] E (197007765) transport_base: poll_read select error 113, errno = Software caused connection abort, fd = 62
[19761.20h.03m.41s.930] E (197007775) mqtt_client: Poll read error: 119, aborting connection
[19761.20h.03m.41s.935] I (197007775) MQTT: MQTT_EVENT_DISCONNECTED
[19761.20h.03m.41s.941] I (197007785) telnet: Telnet session termination requested
[19761.20h.03m.41s.950] W (197007785) telnet: No action taken - no telnet connection and telnet task not started
[19761.20h.03m.42s.033] I (197007885) WIFI:   event = STA_DISCONECTED - retry # 0 (MAX 5)
[19761.20h.03m.42s.034] W (197007885) WIFI:   connect to the AP failed - retrying
[19761.20h.03m.42s.039] I (197007885) telnet: Start telnetTask()
[19761.20h.03m.42s.053] W (197007905) WIFI: Starting network reconnect task
[19761.20h.03m.42s.053] I (197007905) WIFI: wifiReconnect()
[19761.20h.03m.42s.055] I (197007905) wifi:flush txq
[19761.20h.03m.42s.057] I (197007905) wifi:stop sw txq
[19761.20h.03m.42s.061] I (197007905) wifi:lmac stop hw txq
[19761.20h.03m.42s.064] W (197007905) WIFI: WifiDeinit()
[19761.20h.03m.42s.068] I (197007915) wifi:Deinit lldesc rx mblock:10
[19761.20h.03m.42s.078] I (197007925) WIFI: - Restarting wifi
[19761.20h.03m.42s.078] I (197007925) WIFI: wifiStart()
[19761.20h.03m.42s.084] W (197007925) WIFI:   Wifi driver not started; Calling init and create funcs
[19761.20h.03m.42s.088] I (197007935) WIFI:   Initializing wifi
[19761.20h.03m.42s.093] I (197007935) WIFI:   Setting wifi hostname
[19761.20h.03m.42s.098] I (197007945) pp: pp rom version: e7ae62f
[19761.20h.03m.42s.104] I (197007945) net80211: net80211 rom version: e7ae62f
[19761.20h.03m.42s.112] I (197007965) wifi:wifi driver task: 3fcbab5c, prio:23, stack:6656, core=0
[19761.20h.03m.42s.122] I (197007975) wifi:wifi firmware version: ce9244d
[19761.20h.03m.42s.123] I (197007975) wifi:wifi certification version: v7.0
[19761.20h.03m.42s.124] I (197007975) wifi:config NVS flash: enabled
[19761.20h.03m.42s.129] I (197007975) wifi:config nano formating: disabled
[19761.20h.03m.42s.134] I (197007975) wifi:Init data frame dynamic rx buffer num: 32
[19761.20h.03m.42s.140] I (197007985) wifi:Init management frame dynamic rx buffer num: 32
[19761.20h.03m.42s.145] I (197007985) wifi:Init management short buffer num: 32
[19761.20h.03m.42s.150] I (197007995) wifi:Init dynamic tx buffer num: 32
[19761.20h.03m.42s.154] I (197007995) wifi:Init static tx FG buffer num: 2
[19761.20h.03m.42s.159] I (197008005) wifi:Init static rx buffer size: 1600
[19761.20h.03m.42s.163] I (197008005) wifi:Init static rx buffer num: 10
[19761.20h.03m.42s.167] I (197008015) wifi:Init dynamic rx buffer num: 32
[19761.20h.03m.42s.172] I (197008015) wifi_init: rx ba win: 6
[19761.20h.03m.42s.176] I (197008025) wifi_init: tcpip mbox: 32
[19761.20h.03m.42s.181] I (197008025) wifi_init: udp mbox: 6
[19761.20h.03m.42s.185] I (197008025) wifi_init: tcp mbox: 6
[19761.20h.03m.42s.189] I (197008035) wifi_init: tcp tx win: 5744
[19761.20h.03m.42s.194] I (197008035) wifi_init: tcp rx win: 5744
[19761.20h.03m.42s.199] I (197008045) wifi_init: tcp mss: 1440
[19761.20h.03m.42s.204] I (197008045) wifi_init: WiFi IRAM OP enabled
[19761.20h.03m.42s.209] I (197008055) wifi_init: WiFi RX IRAM OP enabled
[19761.20h.03m.42s.214] I (197008055) WIFI: MAC Address: 34:85:18:50:7b:88
[19761.20h.03m.42s.220] I (197008065) WIFI:   Calling esp_wifi_start()
[19761.20h.03m.42s.225] I (197008065) wifi:mode : sta (34:85:18:50:7b:88)
[19761.20h.03m.42s.231] I (197008075) wifi:enable tsf
[19761.20h.03m.42s.882] I (197008075) WIFI:   Waiting for event callback...
[19761.20h.03m.42s.882] I (197008725) wifi:new:<6,0>, old:<1,0>, ap:<255,255>, sta:<6,0>, prof:1
[19761.20h.03m.42s.883] I (197008735) wifi:state: init -> auth (b0)
[19761.20h.03m.42s.891] I (197008735) wifi:state: auth -> assoc (0)
[19761.20h.03m.43s.459] I (197009305) SENSORS: Temp: 74.7 (raw: 80.28 F)  Humidity: 31.7 (raw: 19.20)
[19761.20h.03m.43s.892] I (197009735) wifi:state: assoc -> init (2700)
[19761.20h.03m.43s.893] I (197009745) wifi:new:<6,0>, old:<6,0>, ap:<255,255>, sta:<6,0>, prof:1
[19761.20h.03m.43s.897] I (197009745) telnet: Telnet session termination requested
[19761.20h.03m.43s.904] I (197009745) telnet: Starting new telnet service instance
[19761.20h.03m.44s.022] I (197009875) WIFI:   event = STA_DISCONECTED - retry # 0 (MAX 5)
[19761.20h.03m.44s.024] W (197009875) WIFI:   connect to the AP failed - retrying
[19761.20h.03m.44s.029] I (197009875) telnet: Start telnetTask()
[19761.20h.03m.45s.237] I (197011085) wifi:new:<11,0>, old:<6,0>, ap:<255,255>, sta:<11,0>, prof:1
[19761.20h.03m.45s.239] I (197011085) wifi:state: init -> auth (b0)
[19761.20h.03m.45s.243] I (197011095) wifi:state: auth -> assoc (0)
[19761.20h.03m.45s.249] I (197011095) wifi:state: assoc -> run (10)
[19761.20h.03m.45s.286] I (197011135) wifi:connected with <ssid>, aid = 2, channel 11, BW20, bssid = f0:9f:c2:a7:10:90
[19761.20h.03m.45s.288] I (197011135) wifi:security: WPA2-PSK, phy: bgn, rssi: -64
[19761.20h.03m.45s.297] I (197011145) wifi:pm start, type: 1
[19761.20h.03m.45s.297]
[19761.20h.03m.45s.300] I (197011145) wifi:set rx beacon pti, rx_bcn_pti: 0, bcn_timeout: 25000, mt_pti: 0, mt_time: 10000
[19761.20h.03m.45s.308] I (197011155) wifi:<ba-add>idx:0 (ifx:0, f0:9f:c2:a7:10:90), tid:0, ssn:0, winSize:64
[19761.20h.03m.45s.352] I (197011195) wifi:AP's beacon interval = 102400 us, DTIM period = 3
[19761.20h.03m.46s.304] I (197012155) esp_netif_handlers: sta ip: 192.168.0.71, mask: 255.255.255.0, gw: 192.168.0.254
[19761.20h.03m.46s.309] I (197012155) WIFI:   event = IP_EVENT_STA_GOT_IP - ip: 192.168.0.71
[19761.20h.03m.46s.315] I (197012155) WIFI: connected to ap SSID:<ssid> password:****
[19761.20h.03m.51s.943] E (197017795) esp-tls: Failed to create socket (family 2 socktype 1 protocol 0)
[19761.20h.03m.51s.947] E (197017795) transport_base: Failed to open a new connection: 32770
[19761.20h.03m.51s.953] E (197017795) mqtt_client: Error transport connect
[19761.20h.03m.51s.957] I (197017805) MQTT: MQTT_EVENT_ERROR
[19761.20h.03m.51s.962] I (197017805) MQTT: MQTT_EVENT_DISCONNECTED
[19761.20h.03m.51s.968] I (197017805) telnet: Telnet session termination requested
[19761.20h.03m.51s.974] I (197017815) telnet: Starting new telnet service instance
[19761.20h.03m.52s.098] I (197017945) telnet: Start telnetTask()
[19761.20h.03m.52s.118] E (197017965) telnet: bind: 9 (Bad file number)
[19761.20h.03m.52s.118] I (197017965) telnet: Completing telnetTask()
[19761.20h.03m.53s.538] I (197019385) SENSORS: Temp: 74.7 (raw: 80.24 F)  Humidity: 31.5 (raw: 18.91)
[19761.20h.04m.02s.094] E (197027945) esp-tls: Failed to create socket (family 2 socktype 1 protocol 0)
[19761.20h.04m.02s.097] E (197027945) transport_base: Failed to open a new connection: 32770
[19761.20h.04m.02s.103] E (197027945) mqtt_client: Error transport connect
[19761.20h.04m.02s.127] I (197027955) MQTT: MQTT_EVENT_ERROR
[19761.20h.04m.02s.127] I (197027955) MQTT: MQTT_EVENT_DISCONNECTED
[19761.20h.04m.02s.127] I (197027965) telnet: Telnet session termination requested
[19761.20h.04m.02s.127] E (197027965) telnet: closesocket: 9 (Bad file number)
[19761.20h.04m.02s.135] Guru Meditation Error: Core  0 panic'ed (StoreProhibited). Exception was unhandled.
[19761.20h.04m.02s.135]
[19761.20h.04m.02s.135] Core  0 register dump:
[19761.20h.04m.02s.135] PC      : 0x403820d5  PS      : 0x00060d33  A0      : 0x80380397  A1      : 0x3fccb060
[19761.20h.04m.02s.146] A2      : 0x3fcc6744  A3      : 0x00060d20  A4      : 0x00000000  A5      : 0x00060d23
[19761.20h.04m.02s.157] A6      : 0xb33fffff  A7      : 0xb33fffff  A8      : 0x967c967c  A9      : 0x967c967c
[19761.20h.04m.02s.157] A10     : 0x967c967c  A11     : 0x00000000  A12     : 0x00000000  A13     : 0x3fccb050
[19761.20h.04m.02s.168] A14     : 0x3fccb030  A15     : 0x0000000c  SAR     : 0x00000004  EXCCAUSE: 0x0000001d
[19761.20h.04m.02s.179] EXCVADDR: 0x967c9684  LBEG    : 0x400556d5  LEND    : 0x400556e5  LCOUNT  : 0xfffffffc
[19761.20h.04m.02s.190]
[19761.20h.04m.02s.190]
[19761.20h.04m.02s.190] Backtrace: 0x403820d2:0x3fccb060 0x40380394:0x3fccb080 0x4200a198:0x3fccb0a0 0x42004d54:0x3fccb0c0 0x420f0385:0x3fccb110 0x420efe0a:0x3fccb140 0x420435cd:0x3fccb180 0x42043817:0x3fccb1a0 0x420438de:0x3fccb1c0 0x42044519:0x3fccb1e0 0x40381589:0x3fccb210
[19761.20h.04m.02s.221]

```

smeisner, 2024-04-29:
PR merged. Will close this ticket for now. PR https://github.com/smeisner/smart-thermostat/commit/59ac7b96bf7138c1e7e79329ab227e04674aebfb

Closed 2024-04-29.

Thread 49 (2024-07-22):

Versioning of software & hardware

DSpeichert, 2024-07-22:
It seems that hardware has versions like v0.5.2 and v0.6.0 (latest), while software/firmware has gotten up to v0.7.3.

At the same time, the tagged v0.7.3 will have PCB/kicad designs of prior versions.

This seems unnecessarily confusing. It does make sense to version firmware & hardware separately (along with breaking changes/incompatibilities between them), is there a better way to do that?

smeisner, 2024-07-23:
Yes...the rate of change between the PCB and the firmware is completely different. HW and FW will always have different version numbers.

The issue with the PCB CAD files is related to the long development & test time for each PCB. While working in KiCad, I do not know if the mods I am making will be worthy of a new rev number until I place an order, wait for manufacturing, shipping and then populating the board and finally testing it. That could easily be 2 - 3 months of time.

The version numbering of the KiCad files will align with current releases once I get passed the beta phase. I would like to set the FW and PCB @ V1.0.0 upon "public" release.

smeisner, 2024-07-23:
Actually, the more I think about this, the more I realize I want to have a versioning scheme that will make it obvious what FW versions will work on what PCB versions. For ex, if there is something new in version 2.0 of the PCB, then only FW versions that start with V2.x.x will work on that HW. Conversely, FW V2.x.x will work on any V2.x version of the PCB. If there is a breaking change, major version numbers must change as well.

Does that work?

jrtaylor71, 2025-01-27:
Is there software for version 0.6.0 hardware?

smeisner, 2025-01-27:
> Is there software for version 0.6.0 hardware?

There is, but do you actually have a v0.6.0 prototype?

I will need to look up the details of that HW, but I believe the latest sw will work on 0.6.0.

jrtaylor71, 2025-01-28:
Yes I had several made as it was cheaper. I also have hardware to assemble a few. The v0.6.0 hardware is going to be hard for the average person to assemble as some of the small parts require hot air assemble with a microscope.

I am a retired communications engineer so this kind of stuff was part of my day to day job just not programming. I can help with the hardware for this project. I have limited C coding abilities but from what I can tell the pin numbers used on hardware 0.4.0 and 0.6.0 are different.

smeisner, 2025-01-30:
> Yes I had several made as it was cheaper. I also have hardware to assemble a few. The v0.6.0 hardware is going to be hard for the average person to assemble as some of the small parts require hot air assemble with a microscope.

After going thru all of the historical data, I have created a sheet detailing the use & change of GPIO pins. As of V0.3/0.4, the pins have not changed much to V0.6 of the HW:
- SWD interface was removed (IO 39, 40, 41, 42) <-- it was not useful
- LD2410 Serial interface was added (IO 15& 16) <-- LD2410 used for human detection
- General purpose UART was added (IO 36 & 37) <-- Used for serial logging
- USB interface was added (IO 19, 20) <-- Use the D1 Mini USB interface

If I recall correctly, the version you have has the Lolin D1 Mini on it, right?

If all my research is accurate (the details above), then using the latest firmware will still work. You won't get person detection as you approach the unit (to bring up the touch screen backlight) and you need to use the D1 Mini USB interface for programming & data logging.

Let me know if I have things wrong or if you need help.

Steve

>
> I am a retired communications engineer so this kind of stuff was part of my day to day job just not programming. I can help with the hardware for this project. I have limited C coding abilities but from what I can tell the pin numbers used on hardware 0.4.0 and 0.6.0 are different.

jrtaylor71, 2025-02-01:
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

No it uses the with a USB_C_Receptacle_USB2.0.

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

smeisner, 2025-02-01:
.
> >
> > After going thru all of the historical data, I have created a sheet detailing the use & change of GPIO pins. As of V0.3/0.4, the pins have not changed much to V0.6 of the HW:

> > If I recall correctly, the version you have has the Lolin D1 Mini on it, right?
>
> No, it uses the ESP32-S3-WROOM-1-N16 with a USB_C_Receptacle_USB2.0.

The pictures show v0.6.0. Based on those pics, I can tell you you have the latest released hardware. The pin definitions in the firmware will work.

Steve

jrtaylor71, 2025-02-01:
OK I will let you know when I finish getting one put together.

jrtaylor71, 2025-02-20:
I have not have time to get a board put together so I just ordered some more and them put together. The BOM is missing a few components like relays, buzzer and headers are not a big deal but BR1, r6, r7 and r12 is missing.

smeisner, 2025-02-20:
Yes, completely intentional. These are either components JLCPCB could not source, or were thru-hole components I could solder in later and cheaper.

jrtaylor71, 2025-02-20:
Could you list the headers and buzzer that you planned? I have the other parts.

smeisner, 2025-02-20:
A lot more than you asked for, but I supplied everything I see missing in your photo.

- BZ1: TDK PS1240P02BT
-- https://www.digikey.com/en/products/detail/tdk-corporation/PS1240P02BT/935924
- K1 - K5 Relays: Kemet 551-UC2-3NJ
-- https://content.kemet.com/datasheets/KEM_R7005_UC2_UD2.pdf
-- I believe Mouser had the best price on these
- BR1: MB6S
-- https://www.smc-diodes.com/propdf/ABS22%20THRU%20ABS210%20N1924%20REV.A.pdf
- R12: GL5537 / LDR07
-- http://www.tme.eu/de/Document/f2e3ad76a925811312d226c31da4cd7e/LDR07.pdf
-- https://www.amazon.com/gp/product/B01M3TO7RA
- J3: Phoenix Screw Terminal Block
-- https://www.digikey.com/en/products/detail/on-shore-technology-inc/OSTVN10A150/1588870
- The LD2410 motion sensor:
-- https://www.aliexpress.us/item/3256804932047824.html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

J2, J5, J6 are just the common 2.54 pitch pin headers (For J6 I use a right angle one and point them downward)

smeisner, 2025-02-20:
And just so you know...the "JLCJLCJLCJLC" is a string used by JLCPCB as an indicator where to put the production number. You need to select "Order Number (Specify Position)":

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

jrtaylor71, 2025-02-20:
Thanks, I have a touch screen. Thanks for the JLCPCB info

jrtaylor71, 2025-02-20:
This is the I got.

DIANN 3.2" ILI9341 SPI TFT LCD Display Touch Panel 320x240 TFT LCD Touch Screen Shield 5V/3.3V STM32 Display Module SPI Serial with Touch Pen
https://a.co/d/9GtUCAT

smeisner, 2025-02-20:
Yeah, that's the same one I am using. Originally when I was first starting out, I got this one:
https://www.amazon.com/dp/B0B1M9S9V6

The ones from aliexpress are the same...just much cheaper.

jrtaylor71, 2025-02-25:
What is the CLI command to write the firmware to flash without building it? If I build the current 0.7.4 there is no wifi scanning. It just says no-ssid.

smeisner, 2025-02-26:
If you want to fix this yourself, swap lines 151 & 152 in wifi.c :

```
ESP_ERROR_CHECK(esp_wifi_scan_get_ap_records(&number, ap_info));
ESP_ERROR_CHECK(esp_wifi_scan_get_ap_num(&ap_count));

```
to

```
ESP_ERROR_CHECK(esp_wifi_scan_get_ap_num(&ap_count));
ESP_ERROR_CHECK(esp_wifi_scan_get_ap_records(&number, ap_info));

```
The side effects of the `esp_wifi_scan_get_ap_num()` call was changed to reset the number of APs found. Putting it first maintains the count of APs found.

This discussion should be under its own issue. We have successfully hijacked the original intent of this issue.

smeisner, 2025-02-26:
Issue #63 has been created. Please continue discussion there.

smeisner, 2025-03-19:
Moving this Issue to the Discussions section.

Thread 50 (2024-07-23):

Cold boot into bootloader

DSpeichert, 2024-07-23:
From GettingStarted.md:

> NB #3: If the board has been powered off for a bit, it starts up in boot mode when power is applied. Therefore, the reset button must be pushed. I am guessing this is a power-up problem...if anyone can suggest a PCB change, I will include it in the next run!

Potentially related:
* https://esp32.com/viewtopic.php?t=14147
* https://esp32.com/viewtopic.php?t=31185
* https://github.com/espressif/esp-idf/issues/11448
* https://github.com/espressif/arduino-esp32/issues/577
* https://github.com/mu-editor/mu/issues/2313

Console output from UART0 when power is applied after being "off" overnight:
```
ESP-ROM:esp32s3-20210327
Build:Mar 27 2021
rst:0x1 (POWERON),boot:0x0 (DOWNLOAD(USB/UART0))
waiting for download
```

jrtaylor71, 2025-03-20:
Per the data sheet that is incorrect. See pdf pages 29-30 and 45.

https://www.espressif.com/sites/default/files/documentation/esp32-s3-wroom-1_wroom-1u_datasheet_en.pdf

**By default, GPIO0, GPIO45, and GPIO46 are connected to the chip’s internal pull-up/pull-down resistors.** See pdf page 534.

https://www.espressif.com/sites/default/files/documentation/esp32-s3_technical_reference_manual_en.pdf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

Not trying to argue but I have 30+ of doing this.

smeisner, 2025-03-20:
Two things to consider:
1. This unit is still a prototype, as indicated in the silkscreen of the PCB
2. A thermostat device is an "always-on" device. Power-up is not a primary concern right now, especially with a simple workaround (press the reset button). HVAC features and reliable communications is the current primary concern.

Another point to mention, you stated you figured it out (remove the capacitor).

I too am not "trying to argue" especially since I have not yet researched this topic fully. But, I am going to set priorities as I see fit and right now developing the firmware is a higher priority.

smeisner, 2025-03-21:
Thanks for the feedback on the board design. I hadn't had anyone review it yet.

I did spend some time reading the docs you linked and can tell you are correct that capacitor was the cause of the problem. My prior comment regarding the pull up resistor was my "drive by" solution I had ...I had not yet done the analysis and proper review of the idea. I was quick to assume IO0 was left floating and causing the issue...which wasn't the case at all.

My updated PCB design has already removed C7.

jrtaylor71, 2025-03-21:
The only other thing that I saw was that the internal layers are a little close to the threw holes for mounting. We use to keep them outside the expected screw or mounting post outer diameter size.

smeisner, 2025-04-16:
Latest prototype removes the "debounce capacitor" (C7 on V0.6) and problem is gone.

Closed 2025-04-16.

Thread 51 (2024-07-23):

Is UART/Serial port redundant?

DSpeichert, 2024-07-23:
Apparently, the USB-Serial-JTAG is unique to ESP-S3/C3 and effectively provides power, firmware upload and logging and thus it can send logs unless in deep-sleep mode (or disconnected).

Do we ever expect to need two serial interfaces for logging? Or is one specifically to be used for REPL?

[USB-SERIAL-JTAG docs](https://docs.espressif.com/projects/esp-iot-solution/en/latest/usb/usb_overview/usb_serial_jtag.html)

smeisner, 2024-07-28:
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

Yes, it is unique to the S3 and is utilized by this prototype for FW upload and debugging. The other UART built into the S3 is used to program the LD2410 presence sensor. As described elsewhere, currently this is a prototype and the use of these 2 UARTs is redundant on purpose.

smeisner, 2024-07-28:
Also, please refer to issue #45  for future use of UART port

Closed 2024-07-28.

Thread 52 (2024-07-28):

Battery backup to avoid rapid cycling when power flickers

DSpeichert, 2024-07-28:
Battery backup could help avoid dangerously frequent cycles during flickering power (commonly recommended is minimum 2 minutes of on/off time for AC).

Alternatively, a mandated 2 minute "off" time upon power up could be enforced in firmware.

smeisner, 2024-07-28:
Once again...this is a prototype. There will be no battery backup added to this design. The cost is already is a bit much for this unit and we need ways to lower it. All of the relevant data is stored n NVRAM so there is no need for battery backup as of yet.

The idea of a delay is fine, but 2 minutes is useless. What I've been playing with is more like 15 seconds. Today's HVAC systems already take care of what you're referring to ... and thermostats today (many of the so-called smart ones) don't have any built in delay at all.

I am also investigating delays after changing the target temp. In other words, once the user sets a target temp, wait 2 seconds before commiting the change. This is useful while the user stands there thinking if that's the right temp they actually want.

smeisner, 2024-07-28:
I also have a super capacitor (as mentioned in one of the intro docs) to see if that would work as a short-term "battery" backup. Again, due to the cost, I am not sure it's worth it.

Closed 2024-07-28.

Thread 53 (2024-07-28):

Realign LED, buttons and light sensor with touch screen

DSpeichert, 2024-07-28:
For a usable & aesthetic case design:

* raise RGB LED to touchscreen level
* raise RESET/BOOT buttons to almost touchscreen level
* lower/move/hide C6 capacitor (it protrudes too close to screen height)
* Rotate 90 degrees the UART port so it can be connected from the bottom/side

smeisner, 2024-07-28:
> For a usable & aesthetic case design:
>
> * raise RGB LED to touchscreen level

The intent of this device is not to have any buttons or indicators that aren't required/useful, as mentioned in the README.md.

> * raise RESET/BOOT buttons to almost touchscreen level

The intent of this device is not to have any buttons or indicators that aren't required/useful, as mentioned in the README.md.

> * lower/move/hide C6 capacitor (it protrudes too close to screen height)

This is a side effect of the prototype to create the smallest amount of AC ripple as possible. This cap will not be part of the final designed, as we discussed in email.

> * Rotate 90 degrees the UART port so it can be connected from the bottom/side

Already done in the latest version of the PCB.

Closed 2024-07-28.

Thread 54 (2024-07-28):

24VAC power tolerance

DSpeichert, 2024-07-28:
The HVAC's "24VAC" in the wild could measure up to 27-28VAC.

Honeywell T4 thermostat has [tolerance for 20-30 VAC](https://digitalassets.resideo.com/damroot/Original/10014/33-00614EFS.pdf):
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

smeisner, 2024-12-17:
@DSpeichert Were you citing a problem here? I believe the thermostat may handle this range of input voltages. The LM2596T-5 can handle up to 45V input and the MB6S rectifier can handle even more. So is there a problem you are seeing?

DSpeichert, 2024-12-30:
I honestly don't remember anymore, I was likely not aware of the actual tolerance currently supported by the board. This is mostly an information/documentation thing to make keep some tolerance in the design (especially if you plan to simplify the power handling).

smeisner, 2025-02-27:
Closing due to inactivity. Feel free to reopen if this is an issue.

Closed 2025-02-27.

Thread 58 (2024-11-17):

Serial console setup

smeisner, 2024-11-17:
Allow the use of the USB/serial UART to perform initial setup. To get around problems such as adding wifi credentials, or to avoid enabling wifi altogether, the serial interface can be used as a setup mechanism.

smeisner, 2024-11-17:
Duplicate of issue #45

Closed 2024-11-17.

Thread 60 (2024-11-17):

Research possibility to use SDCard on touchscreen

smeisner, 2024-11-17:
The touchscreen in use includes a SDCard slot. The pins are not wired into the thermostat board. Would it be possible to enable use of this HW? If so, configs, logs, stack traces, etc could be stored on it. Also could be used for FW updates.

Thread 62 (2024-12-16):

Are the 3v3 and GND layers actually necessary?

DieKatzchen, 2024-12-16:
They cause the manufacturing cost to skyrocket. a 101.5mm x 83.4mm four layer board costs me ~$140, a two-layer instead costs ~$25. If 1.5mm could be trimmed off the long edge it would bring it down to ~$5.

smeisner, 2024-12-16:
I have been using JLCPCB and I see nothing costing this much. Which PCB manufacturer are you using?

Are the 2 layers necessary? No. But since this is a prototype and routing is already tricky, it facilitates the firmware development. Feel free to email me directly at: steve at meisners dot net and we can discuss other arrangements if you want.

DieKatzchen, 2024-12-17:
Huh, I didn't realize JLCPCB had such reasonable 4-layer pricing. I was using PCBWAY. Now the only problem is that they have a shortfall of some of the 0603 resistors and I really don't feel like hand-soldering 0603s. I suppose there's no rush.

smeisner, 2024-12-17:
If you are interested in **contributing** to this project, I do have a thermostat (fully assembled and tested) I can send you. If interested, let me know.

DieKatzchen, 2024-12-17:
What kind of contribution do you need? I'm not particularly good at hardware development, but I'm decent at software. If you're using Platformio I've used it before, on Espressif chips even.

smeisner, 2024-12-17:
> What kind of contribution do you need? I'm not particularly good at hardware development, but I'm decent at software. If you're using Platformio I've used it before, on Espressif chips even.

Yes, the project (under the "App" folder) is fully PlatformIO based and ESP-IDF based. Take a look at the Issues tab here on Github and at the code and let me know what you think.

DieKatzchen, 2024-12-18:
I'll take a look later. Currently really busy, but hopefully less so soon.

smeisner, 2024-12-18:
Sure. Let me know if you need any help.

smeisner, 2025-02-26:
Closing due to lack of activity. Feel free to reopen in desired.

Closed 2025-02-26.

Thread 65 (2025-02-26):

Addition of external temp sensor

jrtaylor71, 2025-02-26:
I would be nice to see an an option for an external temp sensor like a DS18B20 for hydronic heating and outdoor boiler applications. This would allow the fans to be shutdown or internal pumps when the incoming water temp gets below a certain point. A typical heating system like this runs between 150 and 180 degF. This way you are not pulling heat from the building you are trying to heat. I would add this to the web interface and not the display.

smeisner, 2025-02-26:
This is a good idea. What I originally had in mind was utilizing a sensor (maybe via HomeAssistant) that supplied the temperature. What you're suggesting is a hardware interface for a local temp sensor? Maybe adding a screw terminal for the 18B20?

jrtaylor71, 2025-02-26:
18B20 or similar would be best as they could be installed in a temperature well. This way they get the best reading. I built a monitor for my boiler that uses a kc868-am with 18b20 sensors and they get the same reading as the gauge on the boiler.

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

smeisner, 2025-04-07:
@jrtaylor71 The board has 3 GPIO (33, 34 and 35) pins broken out and are available for general use. Can these be used for what you are thinking?

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

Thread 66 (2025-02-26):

mqtt not working

jrtaylor71, 2025-02-26:
No mqtt connection atempt to home assistant. I tried with and without port number at the end of the broker address. I will post debug info when I have the serial port connected.

smeisner, 2025-02-26:
Can you also telnet to the thermostat and issue a "status" command. Please provide that info as well.

jrtaylor71, 2025-02-26:
Settings are randomly being lost when using the reset button. It is connected now but when I first looked at the mqtt was enabled but status was disabled. Then I reset it and the display showed it was disabled. So I enabled it and then that when it connected.

The same thing is happening with the cool and fan setting.

`Current Status:
--------------------------------------------------------
Firmware version: 0.7.4
Firmware build date: Feb 26 2025 - 07:45:58
Device name: thermostat
Friendly name: Thermostat
Uptime: 0 days, 00:00:16
Free Heap size: 142496
MAC Address: f0:9e:9e:54:d3:74
Wifi SSID: jonn
Wifi connected: Yes
Wifi signal: 100%
Wifi IP address: 192.168.183.104
Current time: 13:57:08    Timezone: GMT-6
MQTT Enabled: Yes
MQTT Connected: Yes
MQTT Broker: 192.168.183.238  Port: 1883
MQTT Username:  mqtt2
MQTT Password:  mqttxxxxxxx
Current temp: 79.7 F (Correction: -4.8)
Current humidity: 40.9% (Correction: 10.0)
Target temp: 69.0
Swing temp: 1.5
Light detected: 1594
Motion detected: No
Display sleep time: 70
Touch screen beep: Enabled
Current HVAC mode set: Off (Currently: Off)
HVAC modes enabled:
  Heat: True  Cool: False  Fan: False
  2-stage heating enabled: False
  Reversing valve (heat pumps): False
`

`
Current Status:
--------------------------------------------------------
Firmware version: 0.7.4
Firmware build date: Feb 26 2025 - 07:45:58
Device name: thermostat
Friendly name: Thermostat
Uptime: 0 days, 00:01:12
Free Heap size: 139932
MAC Address: f0:9e:9e:54:d3:74
Wifi SSID: jonn
Wifi connected: Yes
Wifi signal: 100%
Wifi IP address: 192.168.183.104
Current time: 13:58:58    Timezone: GMT-6
MQTT Enabled: Yes
MQTT Connected: Yes
MQTT Broker: 192.168.183.238  Port: 1883
MQTT Username:  mqtt2
MQTT Password:  mqttxxxxxxx
Current temp: 79.8 F (Correction: -4.8)
Current humidity: 41.4% (Correction: 10.0)
Target temp: 70.0
Swing temp: 1.5
Light detected: 1553
Motion detected: No
Display sleep time: 70
Touch screen beep: Enabled
Current HVAC mode set: Off (Currently: Off)
HVAC modes enabled:
  Heat: True  Cool: False  Fan: False
  2-stage heating enabled: False
  Reversing valve (heat pumps): False
`

jrtaylor71, 2025-02-27:
See below... All i did was press the reset button.

`Current Status:
--------------------------------------------------------
Firmware version: 0.7.4
Firmware build date: Feb 26 2025 - 07:45:58
Device name: thermostat
Friendly name: Thermostat
Uptime: 0 days, 21:59:17
Free Heap size: 145072
MAC Address: f0:9e:9e:54:d3:74
Wifi SSID: jonn
Wifi connected: Yes
Wifi signal: 100%
Wifi IP address: 192.168.183.104
Current time: 11:57:04    Timezone: GMT-6
MQTT Enabled: Yes
MQTT Connected: Yes
MQTT Broker: 192.168.183.238  Port: 1883
MQTT Username:  mqtt2
MQTT Password:  mqtt652479
Current temp: 77.9 F (Correction: -4.8)
Current humidity: 38.0% (Correction: 10.0)
Target temp: 70.0
Swing temp: 1.5
Light detected: 1976
Motion detected: No
Display sleep time: 70
Touch screen beep: Enabled
Current HVAC mode set: Off (Currently: Off)
HVAC modes enabled:
  Heat: True  Cool: True  Fan: True
  2-stage heating enabled: False
  Reversing valve (heat pumps): False
`
`Current Status:
--------------------------------------------------------
Firmware version: 0.7.4
Firmware build date: Feb 26 2025 - 07:45:58
Device name: thermostat
Friendly name: Thermostat
Uptime: 0 days, 00:00:15
Free Heap size: 141836
MAC Address: f0:9e:9e:54:d3:74
Wifi SSID: jonn
Wifi connected: Yes
Wifi signal: 100%
Wifi IP address: 192.168.183.104
Current time: 11:57:28    Timezone: GMT-6
MQTT Enabled: Yes
MQTT Connected: Yes
MQTT Broker: 192.168.183.238  Port: 1883
MQTT Username:  mqtt2
MQTT Password:  mqtt652479
Current temp: 78.3 F (Correction: -4.8)
Current humidity: 41.0% (Correction: 10.0)
Target temp: 70.0
Swing temp: 1.5
Light detected: 1967
Motion detected: No
Display sleep time: 70
Touch screen beep: Enabled
Current HVAC mode set: Off (Currently: Off)
HVAC modes enabled:
  Heat: True  Cool: False  Fan: False
  2-stage heating enabled: False
  Reversing valve (heat pumps): False
`

smeisner, 2025-03-03:
@jrtaylor71 I have tried what you described multiple times and do not encounter the same problem you are citing. I just wrote the exact steps ([Initial Setup](https://github.com/smeisner/smart-thermostat/blob/main/InitialSetup.md)) I use after a complete erase and start from the beginning.

jrtaylor71, 2025-03-03:
The only I have not tried is to ease and then re-upload.

jrtaylor71, 2025-03-04:
No change. The erase of the esp32-wroom made no difference. It does connect to the mqtt server without a problem. Not sure what changed. Going to close this and open a new issue as what is happening now is a settings save issue on reset.

Closed 2025-03-04.

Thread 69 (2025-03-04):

Fan and cooling settings lost when reset button pushed.

jrtaylor71, 2025-03-04:
Fan and cooling settings lost when reset button pushed. These seem to be the only 2 settings that are lost.

v0.6.0 hardware with ESP32-S3-WROOM-1-N16 LCSC #C2913199

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

Current Status:
--------------------------------------------------------
Firmware version: 0.7.4
Firmware build date: Mar  3 2025 - 17:15:59
Device name: thermostat
Friendly name: Thermostat
Uptime: 0 days, 00:08:27
Free Heap size: 143816
MAC Address: f0:9e:9e:54:d3:74
Wifi SSID: jonn
Wifi connected: Yes
Wifi signal: 100%
Wifi IP address: 192.168.183.104
Current time: 11:58:00    Timezone: GMT-6
MQTT Enabled: Yes
MQTT Connected: Yes
MQTT Broker: 192.168.183.238  Port: 1883
MQTT Username:  mqtt2
MQTT Password:  xxxxxxxxx
Current temp: 76.4 F (Correction: -4.8)
Current humidity: 37.4% (Correction: 10.0)
Target temp: 70.0
Swing temp: 3.0
Light detected: 749
Motion detected: No
Display sleep time: 60
Touch screen beep: Enabled
Current HVAC mode set: Off (Currently: Off)
HVAC modes enabled:
  Heat: True  Cool: True  Fan: True
  2-stage heating enabled: False
  Reversing valve (heat pumps): False

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

Current Status:
--------------------------------------------------------
Firmware version: 0.7.4
Firmware build date: Mar  3 2025 - 17:15:59
Device name: thermostat
Friendly name: Thermostat
Uptime: 0 days, 00:00:30
Free Heap size: 145972
MAC Address: f0:9e:9e:54:d3:74
Wifi SSID: jonn
Wifi connected: Yes
Wifi signal: 100%
Wifi IP address: 192.168.183.104
Current time: 11:59:25    Timezone: GMT-6
MQTT Enabled: Yes
MQTT Connected: Yes
MQTT Broker: 192.168.183.238  Port: 1883
MQTT Username:  mqtt2
MQTT Password:  xxxxxxxxxx
Current temp: 75.5 F (Correction: -4.8)
Current humidity: 38.2% (Correction: 10.0)
Target temp: 70.0
Swing temp: 3.0
Light detected: 733
Motion detected: No
Display sleep time: 60
Touch screen beep: Enabled
Current HVAC mode set: Off (Currently: Off)
HVAC modes enabled:
  Heat: True  Cool: False  Fan: False
  2-stage heating enabled: False
  Reversing valve (heat pumps): False

jrtaylor71, 2025-03-04:
I went through the code for eeprom.cpp and there is no options to save any of the hvac settings to NVS.

jrtaylor71, 2025-03-06:
Fixed https://github.com/jrtaylor71/smart-thermostat/commit/cb56181b5000f84024ec37209eab96bb55dcc873

smeisner, 2025-03-08:
It looked as though your PR was correct for eeprom.cpp. I hope you create a new PR with just that file in it!

smeisner, 2025-03-08:
And BTW...you were 100% correct. In my prototyping/development work, I hadn't got to saving those parameters yet. I believe there are some other items that are still outstanding as well.

smeisner, 2025-03-08:
@jrtaylor71 Would you like me to merge your code changes in eeprom.cpp? If I do, you don't get acknowledged for your research and work, I don't like that. You should have your name on the mods.

smeisner, 2025-03-09:
I have created PR to add your changes: https://github.com/smeisner/smart-thermostat/pull/72

@jrtaylor71 Would you mind taking a look and approving if it looks right?

smeisner, 2025-03-10:
Closed with PR #72 ...and release 0.8.0

Closed 2025-03-10.

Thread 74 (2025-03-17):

v0.8.0 going to into download mode on cold power up

jrtaylor71, 2025-03-17:
After latest update it goes into download mode only when you do a cold power up. It does takes like 5 min or after power down to do this. After power up it's fine. I tested this on 5 different units and they all do the same thing.

ESP-ROM:esp32s3-20210327
Build:Mar 27 2021
rst:0x1 (POWERON),boot:0x0 (DOWNLOAD(USB/UART0))
waiting for download

After power up. Either reset button or power cycle.

ESP-ROM:esp32s3-20210327
Build:Mar 27 2021
rst:0x1 (POWERON),boot:0x8 (SPI_FAST_FLASH_BOOT)
SPIWP:0xee
mode:DIO, clock div:1
load:0x3fce2810,len:0x15a0
load:0x403c8700,len:0x4
load:0x403c8704,len:0xd20
load:0x403cb700,len:0x2ee4
entry 0x403c8920
I (27) boot: ESP-IDF 5.4.0 2nd stage bootloader
I (27) boot: compile time Mar 16 2025 18:22:40
I (27) boot: Multicore bootloader
I (27) boot: chip revision: v0.2
I (30) boot: efuse block revision: v1.3
I (33) boot.esp32s3: Boot SPI Speed : 80MHz
I (37) boot.esp32s3: SPI Mode       : DIO
I (41) boot.esp32s3: SPI Flash Size : 16MB
I (45) boot: Enabling RNG early entropy source...
I (49) boot: Partition Table:
I (52) boot: ## Label            Usage          Type ST Offset   Length
I (58) boot:  0 nvs              WiFi data        01 02 00009000 00005000
I (65) boot:  1 otadata          OTA data         01 00 0000e000 00002000
I (71) boot:  2 app0             OTA app          00 10 00010000 00640000
I (78) boot:  3 app1             OTA app          00 11 00650000 00640000
I (84) boot:  4 spiffs           Unknown data     01 82 00c90000 00360000
I (91) boot:  5 coredump         Unknown data     01 03 00ff0000 00010000
I (97) boot: End of partition table
I (101) esp_image: segment 0: paddr=00010020 vaddr=3c100020 size=8da68h (580200) map
I (210) esp_image: segment 1: paddr=0009da90 vaddr=3fc9cc00 size=02588h (  9608) load
I (218) esp_image: segment 2: paddr=000a0020 vaddr=42000020 size=fc2f0h (1032944) map
I (400) esp_image: segment 3: paddr=0019c318 vaddr=3fc9f188 size=02928h ( 10536) load
I (407) esp_image: segment 4: paddr=0019ec48 vaddr=40374000 size=18b1ch (101148) load
I (430) esp_image: segment 5: paddr=001b776c vaddr=600fe100 size=0001ch (    28) load
I (439) boot: Loaded app from partition at offset 0x10000
I (440) boot: Disabling RNG early entropy source...
I (450) cpu_start: Multicore app
I (459) cpu_start: Pro cpu start user code
I (459) cpu_start: cpu freq: 240000000 Hz
I (459) app_init: Application information:
I (462) app_init: Project name:     espidf-test
I (467) app_init: App version:      V0.8.0
I (472) app_init: Compile time:     Mar 16 2025 18:22:11
I (478) app_init: ELF file SHA256:  e61b10a285274a70...
I (484) app_init: ESP-IDF:          5.4.0
I (489) efuse_init: Min chip rev:     v0.0
I (493) efuse_init: Max chip rev:     v0.99
I (498) efuse_init: Chip rev:         v0.2
I (503) heap_init: Initializing. RAM available for dynamic allocation:
I (510) heap_init: At 3FCB5148 len 000345C8 (209 KiB): RAM
I (517) heap_init: At 3FCE9710 len 00005724 (21 KiB): RAM
I (523) heap_init: At 3FCF0000 len 00008000 (32 KiB): DRAM
I (529) heap_init: At 600FE11C len 00001ECC (7 KiB): RTCRAM
I (536) spi_flash: detected chip: gd
I (539) spi_flash: flash io: dio
W (544) i2c: This driver is an old driver, please migrate your application code to adapt `driver/i2c_master.h`
I (554) sleep_gpio: Configure to isolate all GPIO pins in sleep state
I (561) sleep_gpio: Enable automatic switching of GPIO sleep configuration
I (569) main_task: Started on CPU0
I (589) main_task: Calling app_main()
E (2059) SENSORS: LD2410: Sensor not connected
I (2069) WIFI: WifiStart()
I (2069) WIFI:   Wifi driver not started; Calling init and create funcs
I (2079) WIFI:   Initializing wifi
I (2079) WIFI:   Setting wifi hostname to: "thermostat"
I (2099) WIFI: MAC Address: f0:9e:9e:54:d3:74
I (2099) WIFI:   Calling esp_wifi_start()
I (2129) WIFI:   Waiting for event callback...
I (4539) WIFI:   event = IP_EVENT_STA_GOT_IP - ip: 192.168.183.104
I (4539) WIFI: Connected to AP SSID: jonn Pre-shared key: Jo****

smeisner, 2025-03-17:
Yes, this issue won't be resolved until I respin the boards. So the fact you are seeing it is expected. It is a PCB hardware issue.

jrtaylor71, 2025-03-17:
What is the problem? Is one of the cpu pins in the wrong state a boot?

jrtaylor71, 2025-03-17:
Did some digging and per https://dl.espressif.com/dl/schematics/esp32_devkitc_v4-sch.pdf you just need to remove C7 across the boot switch.

jrtaylor71, 2025-03-17:
I can confirm that removing C7 fixes the problem.

smeisner, 2025-03-17:
This is a duplicate of #50 . The solution is included in that issue.

smeisner, 2025-03-17:
FYI: C7 is required for debouncing the mechanical switch, The proper fix is a pull up resistor.

jrtaylor71, 2025-03-18:
Per the data sheet that is incorrect. See pdf pages 29-30 and 45.

https://www.espressif.com/sites/default/files/documentation/esp32-s3-wroom-1_wroom-1u_datasheet_en.pdf

By default, GPIO0, GPIO45, and GPIO46 are connected to the chip’s internal pull-up/pull-down resistors. See pdf page 534.

https://www.espressif.com/sites/default/files/documentation/esp32-s3_technical_reference_manual_en.pdf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

Not trying to argue but I have 30+ of doing this.

Closed 2025-03-17.

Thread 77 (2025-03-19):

ESP32-S3-Box-3 expansion board?

wrobelda, 2025-03-19:
Have you considered creating an expansion board for ESP32-S3-Box-3 device? This would greatly reduce the complexity of building an ESP32 thermostat and have extra advantage of being able to use the existing functionality of ESP32-S3-Box-3, including support for voice control under ESPHome.

smeisner, 2025-03-19:
No, that's not within the scope of this project. I wanted to create a freestanding thermostat that would replace existing standard units. This means minimizing the external components to create a reliable device.

Now, having said that, I would absolutely entertain this idea. We could leverage the firmware used here to support this idea.

smeisner, 2025-03-19:
Moving this topic to "Discussions" area.

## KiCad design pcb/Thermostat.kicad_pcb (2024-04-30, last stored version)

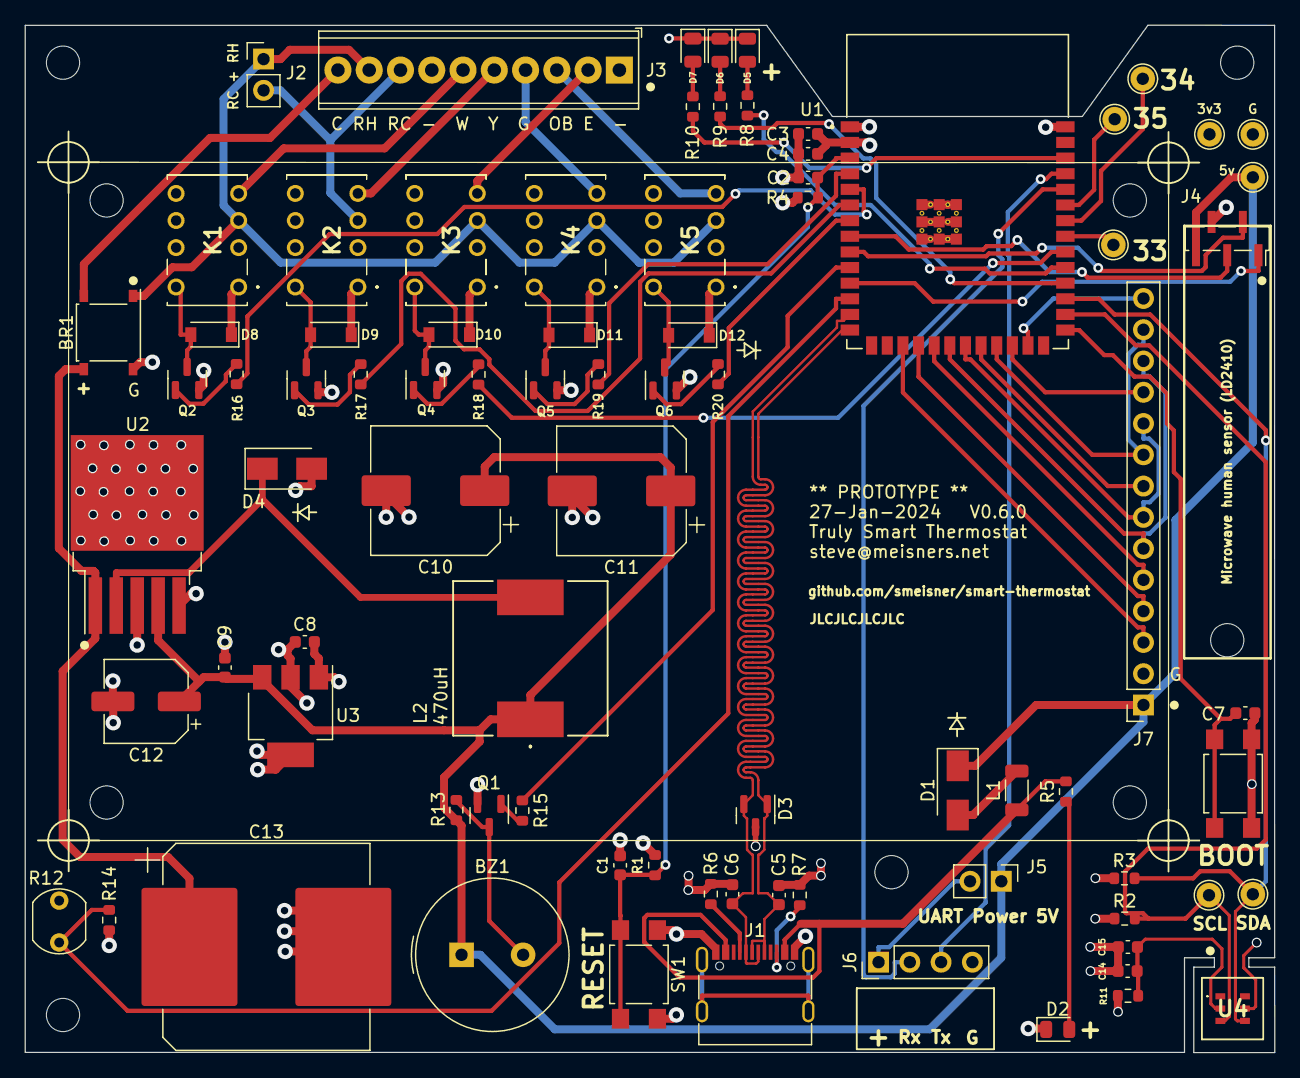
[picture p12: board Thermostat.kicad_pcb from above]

Board: 4 copper layers, 101.5 x 83.4 mm, 92 parts (0 on the bottom side), 65 nets.

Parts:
BR1: MB6S; Diode_Bridge_Diotec_ABS
BZ1: Buzzer; Buzzer_TDK_PS1240P02BT_D12.2mm_H6.5mm
C1, C2, C7: 1uF; C_0603_1608Metric
C3, C14: 0.1uF; C_0603_1608Metric
C4: 22uF; C_0603_1608Metric
C5, C6: 22pF; C_0603_1608Metric
C8, C9, C15: 10uF; C_0603_1608Metric
C10, C11: 470uF; CP_Elec_10x10
C12: 47uF; CP_Elec_6.3x7.7
C13: 680uF; CP_Elec_16x17.5
D1: D_Zener; D_SMA
D2, D5, D6, D7: LED; LED_0805_2012Metric
D3: SP0502BAHT; SOT-23
D4: SS34; D_SMA
D8, D9, D10, D11, D12: 1N4148W; D_SOD-123
H1, H2, H3, H4, H5, H6, H7, H8, H9: MountingHole; MountingHole_2.7mm_M2.5
J1: USB_C_Receptacle_USB2.0; USB_C_Receptacle_G-Switch_GT-USB-7010ASV
J2: RC+RH; PinHeader_1x02_P2.54mm_Vertical
J3: Screw_Terminal_01x10; TerminalBlock_Phoenix_MPT-0,5-10-2.54_1x10_P2.54mm_Horizont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
J4: LD2410; PinSocket_1x05_P1.27mm_Vertical_SMD_Pin1Right
J5: UART PWR; PinHeader_1x02_P2.54mm_Vertical
J6: Conn_01x04; PinHeader_1x04_P2.54mm_Vertical
J7: MSP3218; PinSocket_1x14_P2.54mm_Vertical
K1, K2, K3, K4, K5: UC2-3NJ; UC23NJ
L1: 600ohm; L_1206_3216Metric
L2: 470uH; IND_CDRH127_LDNP-470MC_SUM
Q1, Q2, Q3, Q4, Q5, Q6: 2N7002; SOT-23
R1, R2, R3, R4, R13, R14: 10k; R_0603_1608Metric
R5: 10K; R_0603_1608Metric
R6, R7: 5.1K; R_0603_1608Metric
R8, R10: 1K; R_0603_1608Metric
R9: 2K; R_0603_1608Metric
R11: 220; R_0603_1608Metric
R12: LDR07; R_LDR_5.1x4.3mm_P3.4mm_Vertical
R15: 1k; R_0603_1608Metric
R16, R17, R18, R19, R20: 470; R_0603_1608Metric
SW1: Reset; SW_SPST_TL3305A
SW2: Boot; SW_SPST_TL3305A
TP1: SCL; TestPoint_THTPad_D2.0mm_Drill1.0mm
TP2: SDA; TestPoint_THTPad_D2.0mm_Drill1.0mm
TP3: 3v3; TestPoint_THTPad_D2.0mm_Drill1.0mm
TP4, TP4#2, TP4#3, TP4#4: +5V; TestPoint_THTPad_D2.0mm_Drill1.0mm
TP5: GND; TestPoint_THTPad_D2.0mm_Drill1.0mm
U1: ESP32-S3-WROOM-1-N16; XCVR_ESP32-S3-WROOM-1-N16R2
U2: LM2596T-5; TO-263-5_TabPin3
U3: AMS1117-3.3; SOT-223-3_TabPin2
U4: AHT20

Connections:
+3V3: C3.1, C4.1, C8.1, D8.1 (K), D9.1 (K), D10.1 (K), D11.1 (K), D12.1 (K), K1.1 (COIL+), K2.1 (COIL+), K3.1 (COIL+), K4.1 (COIL+), K5.1 (COIL+), R1.2, R2.1, R3.1, R4.2, R11.2, R12.1, TP3.1, U1.2 (3V3), U3.2 (VO)
+5V: BZ1.1 (-), C9.1, C10.1, C11.1, C12.1, D1.1 (K), J4.5, J5.1, J7.1, L2.1, R13.2, TP4#3.1, U2.4 (FB), U3.3 (VI)
BUZZER: R15.1, U1.10 (IO17)
C: BR1.2, J3.10
E: J3.2, K3.4 (NO_1)
EN: C1.1, C2.1, R1.1, R4.1, SW1.2, U1.3 (EN)
G: J3.4, K4.4 (NO_1)
GND: BR1.4 (-), C1.2, C2.2, C3.2, C4.2, C5.2, C6.2, C7.2, C8.2, C9.2, C10.2, C11.2, C12.2, C13.2, C14.2, C15.2, D2.1 (K), D3.3 (A), D4.2 (A), D5.1 (K), D6.1 (K), D7.1 (K), J1.A1 (GND), J1.A12 (GND), J1.B1 (GND), J1.B12 (GND), J4.4, J6.4, J7.2, Q1.2 (S), Q2.2 (S), Q3.2 (S), Q4.2 (S), Q5.2 (S), Q6.2 (S), R6.2, R7.2, R14.1, SW1.1, SW2.1, TP5.1, U1.1 (GND), U1.40 (GND), U1.41_1 (GND), U1.41_2 (GND), U1.41_3 (GND), U1.41_4 (GND), U1.41_5 (GND), U1.41_6 (GND), U1.41_7 (GND), U1.41_8 (GND), U1.41_9 (GND), U1.41_10 (GND), U1.41_11 (GND), U1.41_12 (GND), U1.41_13 (GND), U1.41_14 (GND), U1.41_15 (GND), U1.41_16 (GND), U1.41_17 (GND), U1.41_18 (GND), U1.41_19 (GND), U1.41_20 (GND), U1.41_21 (GND), U2.3 (GND), U2.5 (~ON/OFF), U3.1 (GND), U4.5 (GND)
HVAC_2STAGE: R18.2, U1.32 (IO39)
HVAC_COOL: R17.2, U1.6 (IO6)
HVAC_FAN: R19.2, U1.4 (IO4)
HVAC_HEAT: R16.2, U1.5 (IO5)
HVAC_RVALV: R20.2, U1.7 (IO7)
LD_RX: J4.3, U1.8 (IO15)
LD_TX: J4.2, U1.9 (IO16)
LED_COOL: R10.2, U1.38 (IO2)
LED_FAN: R9.2, U1.30 (IO37)
LED_HEAT: R8.2, U1.31 (IO38)
LIGHT_SENS: R12.2, R14.2, U1.12 (IO8)
MOTION: J4.1, U1.11 (IO18)
unnamed: BR1.3 (+), C13.1, U2.1 (VIN)
unnamed: BZ1.2 (+), Q1.3 (D), R13.1
unnamed: C7.1, SW2.2, U1.27 (IO0)
unnamed: C14.1, C15.1, R11.1, U4.2 (VDD)
unnamed: D1.2 (A), L1.2
unnamed: D2.2 (A), R5.2
unnamed: D4.1 (K), L2.2, U2.2 (OUT)
unnamed: D5.2 (A), R8.1
unnamed: D6.2 (A), R9.1
unnamed: D7.2 (A), R10.1
unnamed: D8.2 (A), K1.8 (COIL-), Q2.3 (D)
unnamed: D9.2 (A), K2.8 (COIL-), Q3.3 (D)
unnamed: D10.2 (A), K3.8 (COIL-), Q4.3 (D)
unnamed: D11.2 (A), K4.8 (COIL-), Q5.3 (D)
unnamed: D12.2 (A), K5.8 (COIL-), Q6.3 (D)
unnamed: J1.A4 (VBUS), J1.A9 (VBUS), J1.B4 (VBUS), J1.B9 (VBUS), L1.1, R5.1
unnamed: J1.A5 (CC1), R6.1
unnamed: J1.B5 (CC2), R7.1
unnamed: Q1.1 (G), R15.2
unnamed: Q2.1 (G), R16.1
unnamed: Q3.1 (G), R17.1
unnamed: Q4.1 (G), R18.1
unnamed: Q5.1 (G), R19.1
unnamed: Q6.1 (G), R20.1
O/B: J3.3, K5.4 (NO_1)
RC: J2.2, J3.8, K2.3 (COM_1)
RH: BR1.1, J2.1, J3.9, K1.3 (COM_1), K3.3 (COM_1), K4.3 (COM_1), K5.3 (COM_1)
RXD0: J6.2, U1.36 (RXD0)
SCL: R2.2, TP1.1, U1.28 (IO35), U4.3 (SCL)
SDA: R3.2, TP2.1, U1.29 (IO36), U4.4 (SDA)
TFT_CLK: J7.7, J7.10, U1.21 (IO13)
TFT_CS: J7.3, U1.17 (IO9)
TFT_DC: J7.5, U1.19 (IO11)
TFT_LED: J7.8, U1.22 (IO14)
TFT_MISO: J7.9, J7.13, U1.23 (IO21)
TFT_MOSI: J7.6, J7.12, U1.20 (IO12)
TFT_RESET: J7.4, U1.18 (IO10)
TOUCH_CS: J7.11, U1.24 (IO47)
TOUCH_IRQ: J7.14, U1.25 (IO48)
TXD0: J6.3, U1.37 (TXD0)
UART_VCC: J5.2, J6.1
USB_D+: C5.1, D3.1 (K), J1.A6 (D+), J1.B6 (D+), U1.14 (IO20)
USB_D-: C6.1, D3.2 (K), J1.A7 (D-), J1.B7 (D-), U1.13 (IO19)
W: J3.6, K1.4 (NO_1)
Y: J3.5, K2.4 (NO_1)

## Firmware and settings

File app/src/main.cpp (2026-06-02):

// SPDX-License-Identifier: GPL-3.0-only
/*
 * main.cpp
 *
 * Primary entry point for starting the thermostat firmware. This module
 * calls all of the start/initialization functions of the thermostat. 
 * A side effect of initialiing the module is all RTOS tasks are started.
 *
 * Copyright (c) 2023 Steve Meisner (steve@meisners.net)
 * 
 * Notes:
 *
 * History
 *  17-Aug-2023: Steve Meisner (steve@meisners.net) - Initial version
 *  30-Aug-2023: Steve Meisner (steve@meisners.net) - Rewrote to support ESP-IDF framework instead of Arduino
 *  11-Oct-2023: Steve Meisner (steve@meisners.net) - Add suport for home automation (MQTT & Matter)
 *  16-Oct-2023: Steve Meisner (steve@meisners.net) - Add restriction for enabling both MQTT & Matter & removed printf's
 * 
 */

#if defined(MATTER_ENABLED) && defined(MQTT_ENABLED)
  #error "Do not enable Matter/CHIP and MQTT at the same time"
#endif

#include "thermostat.hpp"
#include "esp_timer.h"
#include "version.h"
#include "logger.h"

#define TAG "Main"

// Build version strings for other modules to use
const char *VersionString = VERSION_STRING;
const char *VersionCopyright = VERSION_COPYRIGHT;
const char *VersionBuildDateTime = VERSION_BUILD_DATE_TIME;

int64_t millis() { return esp_timer_get_time() / 1000;}

void app_main()
{
  vTaskDelay(pdMS_TO_TICKS(10000)); //@@@

  // Set default log level for all components
  // esp_log_level_set("*", ESP_LOG_WARN);
  // esp_log_level_set("*", ESP_LOG_INFO);
  esp_log_level_set("*", ESP_LOG_DEBUG);

  // Set up logging function to customize the console, telnet and SD Card
  // Logging plumbing and log levels.
  loggerEnableLocalLogging();

  ESP_LOGI (TAG, "IDF version: %s", esp_get_idf_version());
  ESP_LOGD (TAG, "- Free memory: %d bytes", esp_get_free_heap_size());

  // Load configuration from EEPROM
  ESP_LOGI (TAG, "Reading EEPROM");
  eepromInit();

  // Initialize the TFT display
  ESP_LOGI (TAG, "Initializing TFT");
  tftInit();
  // Create the RTOS task to drive the touchscreen
  ESP_LOGI (TAG, "Starting TFT task");
  tftCreateTask();

  ESP_LOGI (TAG, "Initialize SD memory card");
  sd_init();
  // Check if the system is recovering from a crash loop
  sdcard_check_and_save_coredump("/sdcard/coredump.bin");

  // Initialize sensors (temp, humidity, motion, etc)
  ESP_LOGI (TAG, "Initializing sensors");
  sensorsInit();

#ifdef MATTER_ENABLED
  // Start Matter
  ESP_LOGI (TAG, "Starting Matter");
  OperatingParameters.MatterStarted = MatterInit();
#endif

  // Start wifi
  ESP_LOGI (TAG, "Starting wifi (\"%s\", \"%s\")", WifiCreds.ssid, WifiCreds.password);
  ESP_ERROR_CHECK(esp_netif_init());
  OperatingParameters.wifiConnected = 
    // wifiStart(WifiCreds.hostname, WifiCreds.ssid, WifiCreds.password);
    WifiStart(OperatingParameters.DeviceName, WifiCreds.ssid, WifiCreds.password);

#ifdef MQTT_ENABLED
  // Start Matter
  ESP_LOGI (TAG, "Starting MQTT");
  MqttInit();
#endif

  // Called when wifi is started, so no need to call it here
  // // Start SNTP connection to get local time
  // initTimeSntp();

  // Initialize indicators (relays, LEDs, buzzer)
  ESP_LOGI (TAG, "Initializing indicators");
  indicatorsInit();
  initRelays();

  // Start web server
  ESP_LOGI (TAG, "Starting web server");
  webStart();

#ifdef TELNET_ENABLED
  // Start telnet server
  telnetStart();
#endif

  // Create the RTOS task to drive the state machine
  ESP_LOGI (TAG, "Starting state machine task");
  stateCreateTask();

  ESP_LOGI (TAG, "Saving config info");
  saveConfig();

  // Play the startup sound
  audioStartupBeep();
  ESP_LOGI (TAG, "Startup done");
}

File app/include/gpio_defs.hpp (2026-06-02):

#pragma once

//
// Define all the GPIO pins used
//

// HW Version 0.02

// #define LED_BUILTIN 2

// #define LED_HEAT_PIN 0
// #define BUZZER_PIN 4
// #define TOUCH_CS_PIN 5
// #define SWD_TDI_PIN 12
// #define SWD_TCK_PIN 13
// #define SWD_TMS_PIN 14
// #define TFT_CS_PIN 16
// #define HVAC_HEAT_PIN 17
// #define TFT_CLK_PIN 18
// #define HVAC_COOL_PIN 19
// #define TFT_LED_PIN 32
// #define TFT_RESET_PIN 33
// #define TFT_MISO_PIN 34
// #define TOUCH_IRQ_PIN 35
// #define LIGHT_SENS_PIN 36
// #define MOTION_PIN 39
// #define SDA_PIN 21
// #define SCL_PIN 22
// #define TFT_MOSI_PIN 23
// #define HVAC_FAN_PIN 25
// #define LED_COOL_PIN 26
// #define TFT_DC_PIN 27
// //#define LED_IDLE_PIN -1
// #define LED_IDLE_PIN 2

// HW Version 0.04

#define HVAC_FAN_PIN 4
#define HVAC_HEAT_PIN 5
#define HVAC_COOL_PIN 6
#define HVAC_RVALV_PIN 7
#define BUZZER_PIN 17
#define MOTION_PIN 18
#define LIGHT_SENS_PIN 8
#define TFT_CS_PIN 9
#define TFT_RESET_PIN 10
#define TFT_DC_PIN 11
#define TFT_MOSI_PIN 12
#define TFT_CLK_PIN 13
#define TFT_LED_PIN 14
#define LD_RX 15
#define LD_TX 16
#define TFT_MISO_PIN 21
#define TOUCH_CS_PIN 47
#define TOUCH_IRQ_PIN 48
#define SD_CS 40
#define SCL_PIN 35
#define SDA_PIN 36
#define LED_FAN_PIN 37
#define LED_HEAT_PIN 38
#define HVAC_STAGE2_PIN 39
#define GPIO41 41 //@@@ Not used
#define GPIO42 42 //@@@ Not used
#define LED_COOL_PIN 2

// #define SCL 35 //28
// #define SDA 36 //29

/*

Macros to convert GPIO number to ADC channel and vice versa

*/
#define _ADC_TO_GPIO(x) x##_GPIO_NUM
#define ADC_TO_GPIO(x) _ADC_TO_GPIO(x)
#define _GPIO_TO_ADC1(x) ADC1_GPIO##x##_CHANNEL
#define GPIO_TO_ADC1(x) _GPIO_TO_ADC1(x)
#define _GPIO_TO_ADC2(x) ADC2_GPIO##x##_CHANNEL
#define GPIO_TO_ADC2(x) _GPIO_TO_ADC2(x)

// Use some convoluted macro-magic to find the corresponding ADC for a specified GPIO
// Because ADCx_CHANNELx is n Enum, we can't use macro checks to verify which mapping is correct
//  Instead:
//    (1)  map GPIO->ADCx_GPIOy_CHANNEL : This will either result in an enum or an undefined macro
//    (2)  map (1) -> ADCx_CHANNEL_y_GPIO_NUM :
//         If (1) mapped to an enum, this will map back to a GPIO #
//         If (1) did NOT map to an enum, this will map to an empty value
//    (3)  compare (2) to the original GPIO which will only succeed if (1) mapped properly
#if (ADC_TO_GPIO(GPIO_TO_ADC1(CONFIG_BUTTON_INTR_PIN)) == CONFIG_BUTTON_INTR_PIN)
  #if (ADC_TO_GPIO(GPIO_TO_ADC1(CONFIG_GPIO_PIN)) == CONFIG_GPIO_PIN)
    #define CONFIG_ADC_CHAN GPIO_TO_ADC1(CONFIG_GPIO_PIN)
  #elif (ADC_TO_GPIO(GPIO_TO_ADC2(CONFIG_GPIO_PIN)) == CONFIG_GPIO_PIN)
    #define CONFIG_ADC_CHAN GPIO_TO_ADC2(CONFIG_GPIO_PIN)
  #else
    #error "No ADC found for CONFIG_GPIO_PIN"
    #define CONFIG_BUTTON_ADC_CHAN 0
  #endif
#endif

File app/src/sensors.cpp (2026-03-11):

// SPDX-License-Identifier: GPL-3.0-only
/*
 * sensors.cpp
 *
 * This module supports all the sensor devices included with the thermostat. This includes
 * includes the AHT20, the LDR light detector, LD2410 uWave human presence detector and
 * the SNTP provided time.
 *
 * Copyright (c) 2023 Steve Meisner (steve@meisners.net)
 * 
 * Notes:
 *  The DFRobot_AHT20 module was provided on Github and used here to
 *  drive the AHT20 temp/humidity sensor. This module was supplied by DFRobot.
 *
 * History
 *  17-Aug-2023: Steve Meisner (steve@meisners.net) - Initial version
 *  30-Aug-2023: Steve Meisner (steve@meisners.net) - Rewrote to support ESP-IDF framework instead of Arduino
 * 
 */

#include "thermostat.hpp"
#include "esp_intr_alloc.h"
#include "esp_adc/adc_continuous.h"
#include "soc/adc_channel.h"
#include "esp_sntp.h"
#include <aht.h>
#include <timezonedb_lookup.h>
#include <ld2410.h>
#include <Smoothed.h>
#include "esp_adc/adc_oneshot.h"
#include "esp_adc/adc_cali.h"
#include "esp_adc/adc_cali_scheme.h"

static const char *TAG = "SENSORS";

// const char *gmt_timezones[] = 
//   {"GMT-12", "GMT-11", "GMT-10", "GMT-9", "GMT-8", "GMT-7", "GMT-6", "GMT-5", "GMT-4", "GMT-3", "GMT-2",  "GMT-1"
//    "GMT",    "GMT+1",  "GMT+2",  "GMT+3", "GMT+4", "GMT+5", "GMT+6", "GMT+7", "GMT+8", "GMT+9", "GMT+10", "GMT+11"};

const char *gmt_timezones[] = 
  {"GMT+11", "GMT+10", "GMT+9", "GMT+8", "GMT+7", "GMT+6", "GMT+5", "GMT+4", "GMT+3", "GMT+2", "GMT+1",
   "GMT", "GMT-1", "GMT-2", "GMT-3", "GMT-4", "GMT-5", "GMT-6", "GMT-7", "GMT-8", "GMT-9", "GMT-10", "GMT-11", "GMT-12"};

int64_t lastTimeUpdate = 0;

Stream RadarPort;
ld2410 radar;
uint64_t last_ld2410_Reading = 0;

Smoothed<float> sensorTemp;
Smoothed<float> sensorHumidity;

adc_unit_t adcUnit;
adc_channel_t adcChannel;
adc_oneshot_unit_handle_t adcHandle;

void updateHvacMode(HVAC_MODE mode)
{
  OperatingParameters.hvacSetMode = mode;
  eepromUpdateHvacSetMode();
#ifdef MQTT_ENABLED
  MqttUpdateStatusTopic();
#endif
}

void updateHvacSetTemp(float setTemp)
{
  OperatingParameters.tempSet = setTemp;
  eepromUpdateHvacSetTemp();
  ESP_LOGI(TAG, "Set temp: %.1f", setTemp);
#ifdef MQTT_ENABLED
  MqttUpdateStatusTopic();
#endif
}

/*---------------------------------------------------------------
        ADC Code (for light sensor)
---------------------------------------------------------------*/
void initLightSensor()
{
  adc_oneshot_io_to_channel(LIGHT_SENS_PIN, &adcUnit, &adcChannel);

  adc_oneshot_unit_init_cfg_t init_config = {
    .unit_id = adcUnit,
    .clk_src = ADC_RTC_CLK_SRC_DEFAULT,
    .ulp_mode = ADC_ULP_MODE_DISABLE
  };
  ESP_ERROR_CHECK(adc_oneshot_new_unit(&init_config, &adcHandle));

  adc_oneshot_chan_cfg_t config = {
    .atten = ADC_ATTEN_DB_12,
    .bitwidth = ADC_BITWIDTH_DEFAULT,
  };
  ESP_ERROR_CHECK(adc_oneshot_config_channel(adcHandle, adcChannel, &config));
}

int readLightSensor(void)
{
  static int voltage;

  ESP_ERROR_CHECK(adc_oneshot_read(adcHandle, adcChannel, &voltage));
  ESP_LOGV(TAG, "ADC%d Channel[%d] Raw Data: %d", adcUnit + 1, adcChannel, voltage);
  ESP_LOGV(TAG, "Light Sensor: %d mV", (int)voltage);

  return (int)voltage;
}

/*---------------------------------------------------------------
        Functions to convert temp values
---------------------------------------------------------------*/
float getRoundedFrac(float value)
{
  int whole;

  whole = (int)(value);
  float frac = value - (float)(whole);

  if (frac < 0.5)
    return 0;
  // else
  return 5;
}

float roundValue(float value, int places)
{
  float r = 0.0;

  if (places == 0)
    r = (float)((int)(value + 0.5));
  if (places == 1)
    r = (float)((int)(value + 0.25) + (getRoundedFrac(value + 0.25) / 10.0));
  return r;
}

//////////////////////////////////////////////////////////////////////////////////////
//
//    LD2410 support code
//
//////////////////////////////////////////////////////////////////////////////////////

static void IRAM_ATTR MotionDetect_ISR(void *arg)
{
  tftMotionTrigger = true;
}


bool ld2410_init()
{
  bool rc;

  gpio_install_isr_service(0);

  gpio_config_t io_conf;
  io_conf.intr_type = GPIO_INTR_POSEDGE;
  io_conf.mode = GPIO_MODE_INPUT;
  io_conf.pull_down_en = GPIO_PULLDOWN_DISABLE;
  io_conf.pull_up_en = GPIO_PULLUP_DISABLE;
  io_conf.pin_bit_mask = (1ULL<<MOTION_PIN);
  gpio_config(&io_conf);

  //attach isr handler
  gpio_isr_handler_add((gpio_num_t)MOTION_PIN, MotionDetect_ISR, nullptr);

  RadarPort.begin(UART_NUM_2, 256000, LD_RX, LD_TX); //UART for monitoring the radar
  vTaskDelay(pdMS_TO_TICKS(500));

  if (radar.begin(RadarPort))
  {
    ESP_LOGI(TAG, "LD2410: Sensor started");
    rc = true;

    if (radar.requestFirmwareVersion())
    {
      ESP_LOGI(TAG, "LD2410: Firmware: v%u.%02u.%08x",
        radar.firmware_major_version,
        radar.firmware_minor_version,
        radar.firmware_bugfix_version
        );
      snprintf (OperatingParameters.ld2410FirmWare, sizeof(OperatingParameters.ld2410FirmWare),
        "%u.%02u.%08x",
        radar.firmware_major_version,
        radar.firmware_minor_version,
        radar.firmware_bugfix_version
        );
    }
    else
    {
      ESP_LOGE(TAG, "LD2410: Failed to read firmware version\n");
      OperatingParameters.Errors.hardwareErrors++;
      snprintf (OperatingParameters.ld2410FirmWare,
        sizeof(OperatingParameters.ld2410FirmWare),
        "-.--.--------");
    }

    if (radar.requestCurrentConfiguration())
    {
      ESP_LOGI(TAG, "LD2410: Maximum gate ID: %d", radar.max_gate);
      ESP_LOGI(TAG, "LD2410: Maximum gate for moving targets: %d", radar.max_moving_gate);
      ESP_LOGI(TAG, "LD2410: Maximum gate for stationary targets: %d", radar.max_stationary_gate);
      ESP_LOGI(TAG, "LD2410: Idle time for targets: %d", radar.sensor_idle_time);
      ESP_LOGI(TAG, "LD2410: Gate sensitivity");
      for (uint8_t gate = 0; gate <= radar.max_gate; gate++)
      {
        ESP_LOGI(TAG, "  Gate %d moving targets: %d stationary targets: %d",
          gate, radar.motion_sensitivity[gate], radar.stationary_sensitivity[gate]);
      }
    }
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

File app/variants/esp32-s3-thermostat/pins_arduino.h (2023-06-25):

#ifndef Pins_Arduino_h
#define Pins_Arduino_h

#include <stdint.h>
#include "soc/soc_caps.h"

#define USB_VID 0x303a
#define USB_PID 0x1001

#define EXTERNAL_NUM_INTERRUPTS 46
#define NUM_DIGITAL_PINS        48
#define NUM_ANALOG_INPUTS       20

// Some boards have too low voltage on this pin (board design bug)
// Use different pin with 3V and connect with 48
// and change this setup for the chosen pin (for example 38)
static const uint8_t LED_BUILTIN = SOC_GPIO_PIN_COUNT+48;
#define BUILTIN_LED  LED_BUILTIN // backward compatibility
#define LED_BUILTIN LED_BUILTIN
#define RGB_BUILTIN LED_BUILTIN
#define RGB_BRIGHTNESS 64

#define analogInputToDigitalPin(p)  (((p)<20)?(analogChannelToDigitalPin(p)):-1)
#define digitalPinToInterrupt(p)    (((p)<48)?(p):-1)
#define digitalPinHasPWM(p)         (p < 46)

static const uint8_t TX = 43;
static const uint8_t RX = 44;

static const uint8_t SDA = 36;
static const uint8_t SCL = 35;

static const uint8_t SS    = 10;
static const uint8_t MOSI  = 11;
static const uint8_t MISO  = 13;
static const uint8_t SCK   = 12;

static const uint8_t A0 = 1;
static const uint8_t A1 = 2;
static const uint8_t A2 = 3;
static const uint8_t A3 = 4;
static const uint8_t A4 = 5;
static const uint8_t A5 = 6;
static const uint8_t A6 = 7;
static const uint8_t A7 = 8;
static const uint8_t A8 = 9;
static const uint8_t A9 = 10;
static const uint8_t A10 = 11;
static const uint8_t A11 = 12;
static const uint8_t A12 = 13;
static const uint8_t A13 = 14;
static const uint8_t A14 = 15;
static const uint8_t A15 = 16;
static const uint8_t A16 = 17;
static const uint8_t A17 = 18;
static const uint8_t A18 = 19;
static const uint8_t A19 = 20;

static const uint8_t T1 = 1;
static const uint8_t T2 = 2;
static const uint8_t T3 = 3;
static const uint8_t T4 = 4;
static const uint8_t T5 = 5;
static const uint8_t T6 = 6;
static const uint8_t T7 = 7;
static const uint8_t T8 = 8;
static const uint8_t T9 = 9;
static const uint8_t T10 = 10;
static const uint8_t T11 = 11;
static const uint8_t T12 = 12;
static const uint8_t T13 = 13;
static const uint8_t T14 = 14;

#endif /* Pins_Arduino_h */

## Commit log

2023-02-11 Add KiCad files & Armbian NanoPi notes
    [NanoPi_NEO_Air-V1.1-1708.dxf, Thermostat.kicad_pcb, Thermostat.kicad_sch]
2023-02-15 Working temp/humidity sensor
2023-02-21 Updated PCB/SCH - Add motion sensor, indicator lite, AHT20
    [Thermostat.kicad_pcb, Thermostat.kicad_sch]
2023-03-04 V0.01 sent to fab house
    [Thermostat.kicad_pcb, Thermostat.kicad_sch]
2023-03-04 Add 3D model and fixed up footprints
    [Thermostat.kicad_pcb, Thermostat.kicad_sch]
2023-03-12 First test version of ESP code
    [Thermostat.kicad_pcb, Thermostat.kicad_sch]
2023-03-13 V0.01 - Prototype mostly working (RGB LED does not). Changes included for V0.02 prototype to correct problems.
    [Thermostat.kicad_pcb, Thermostat.kicad_sch]
2023-03-15 Add datasheet
    [Thermostat.kicad_pcb, Thermostat.kicad_sch]
2023-03-15 Add Kicad XML file
2023-03-15 Add BOM
    [Thermostat.csv]
2023-03-15 Add 'production' folder
    [bom.csv, designators.csv, positions.csv]
2023-03-19 V0.02 - Updated README and app working (FreeRTOS, interrupts, touch int, motion int, read TP and AHT)
2023-03-25 Identified problems with PCB
    [Thermostat.kicad_sch]
2023-03-26 Added note re: ESP32 SOC
    [Thermostat.kicad_sch]
2023-04-01 Added T&H sensor datasheets
2023-04-03 Remove old NanoPi data files
    [NanoPi_NEO_Air-V1.1-1708.dxf, Thermostat.kicad_pcb, Thermostat.kicad_sch]
2023-04-07 interim checkin for V0.03 prototype
    [Thermostat.kicad_sch]
2023-05-03 Pics of actual prototype board (Prototype #2)
2023-05-13 Fix minor UI bugs
    [tft.cpp]
2023-05-24 Track HVAC mode using internal values; Trying to get web server in RTOS task
2023-05-24 Add fractional part of current & set temp in web page
2023-05-24 Adding screenshots of SLS menus
    [Thermostat.kicad_pcb, Thermostat.kicad_sch]
2023-06-25 V0.4 - Update for V0.4 PCB (ESP32-S3) Stop converting temperatures; Drop the Adafruit lib for AHT; Add board definitons; Use task fro net reconnect
2023-06-26 Update PCB design to V0.5.1
    [Thermostat (Before routing).kicad_pcb, Thermostat-processor.kicad_sch, Thermostat.csv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]
2023-06-26 Added production files for V0.5.1
    [bom.csv, designators.csv, positions.csv]
2023-06-26 Added sample output of doing a build inside a VM
2023-06-30 Update PCB files (v0.5.1)
    [SO12306266019.dxf, Thermostat.kicad_pcb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]
2023-07-06 Update PCB production files to V0.5.2
    [bom.csv, positions.csv]
2023-07-06 Update PCB design for V0.5.2
    [Thermostat-processor.kicad_sch, Thermostat.kicad_pcb, Thermostat.kicad_sch]
2023-07-13 Removed stencil folder and small tweaks to PCB
    [SO12306266019.dxf, Thermostat.kicad_pcb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]
2023-07-13 V0.5.2 PCB files exported as PDF
2023-07-13 Updated STL files to V0.5.2
2023-07-13 Corrected revision info
    [Thermostat-processor.kicad_sch, Thermostat.kicad_sch]
2023-07-13 Update GettingStarted.md
    Added BOM analysis sheet
2023-08-05 Update README.md
    Updated info for LD2410 sensor
2023-09-07 ESP-IDF rewrite - Stage 1
2023-09-07 ESP-IDF rewrite - Stage 2
    [default_16mb.csv]
2023-09-08 Initial sdkconfig.esp32s3
2023-09-08 sdkconfig.esp32-s3-devkitc-1 file added by mistake ... removing
2023-09-26 update web ui to live update
    Changes from arduino libraries to espressif libraries means
    some specifics have to change. This commit has no working buttons
    on the web ui, but all info like light, humidity, and temp readings
    are live.
2023-09-26 fix webui buttons
2023-09-28 add conditional rendering and more hvac controls
    Thermostat settings like fan, cool, and auto shouldn't be visible
    on the web ui if those options aren't available. These settings can
    now be toggled in the web ui and the corresponding buttons in the
    "Thermostat Controls" box won't be shown if they're not enabled.
2023-09-28 add additional hvac system toggles to webui
    2 stage heating and reverse valve toggles
2023-10-16 0.7 - Use friendly name; improve screen UI (device name)
2023-10-26 Remove final printf and unused code.
2023-10-28 Change time vars to 64-bit (wrapped @ 24.85 days); consistent temp setting; stop resetting relays @ start
    [indicators.cpp, main.cpp, sensors.cpp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]
2023-11-24 Use 1 version var, added telnet log monitoring & config, fixed control algorithm
    [main.cpp, sensors.cpp, state_machine.cpp]
2023-11-30 Add error struct, telnet control, eeprom updating
    [sensors.cpp]
2023-12-02 turn on fan pin with heat or cool
2023-12-04 tidy up tftAutoBrightness
    Slightly modified tftAutoBrightness() to fix some noticeable
    flickering at constant ambient light levels, and made other minor
    impprovements.
    [tft.cpp]
2023-12-29 Add motion sensor for MQTT, hvac state routine, cleaned MQTT module. Fixed fan state
    [state_machine.cpp, tft.cpp]
2024-01-02 Send initial state of motion sensor
2024-02-01 Fixed server socket compare
2024-02-01 PCB V0.6.0
    [Thermostat-accessories.kicad_sch, Thermostat-processor.kicad_sch, Thermostat.kicad_pcb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]
2024-02-08 Changes due to new PCB
    With V0.6.0 PCB rev, there are a few changes in the code.
    - New 2nd stage relay
    - Removed SWD port
    - Changed RGB LED to SMD components
    Also added error recovery when AHT sensor doesn't respond.
    [gpio_defs.hpp, indicators.cpp, sensors.cpp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]
2024-04-12 Add MqttReconnect() func and clean up tracking of telnet sockets
2024-04-29 streamline the state-machine code
    Reduce duplicated code by initializing an array describing the GPIO
    pin states for each mode set by the state-machine.
2024-04-29 Fixed mem leaks esp in mqtt, telnet and wifi. Added heap reporting. General code cleanup
    [indicators.cpp, main.cpp, sensors.cpp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]
2024-04-30 PCB updates
    [Thermostat.kicad_pcb, Thermostat.kicad_sch, power_supply-acc.kicad_sch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]
2024-04-30 Corrected print statement for heap stats
2024-05-30 Add v0.6.0 STL files
    [FabConvert.com_thermostat v0.6.0.stl]
2024-08-13 Fix problem with timezone ordering
    [sensors.cpp]
2024-10-03 3D UWP case for prototype
    [thermo-housing-back.stp, thermo-housing-front.stp]
2024-10-03 Moved files
    [thermo-housing-back.stp, thermo-housing-front.stp]
2025-03-03 Create InitialSetup.md
    Add documentation for steps to initially set up wifi, the device name and MQTT.
2025-03-08 Add '?' for help, LD2410 fw, better heap info, log level. Also, do proper socket cleanup
2025-03-09 V0.8.0: Major overhaul for wifi. Fix scanning; Better tracking of states & error recovery
    [main.cpp]
2025-03-09 Fixed missing block of code
    [main.cpp]
2025-03-18 Fixed socket leak when AP connection is lost
2025-04-22 Pin ld2410 library to 0.1.3 becasue 0.1.4 is broken, and 0.1.5 is not yet released in platformio
2025-04-22 Moved PCB design and data sheets to a separate repo
    [FabConvert.com_thermostat v0.6.0.stl, Thermostat (Before routing).kicad_pcb, Thermostat-accessories.kicad_sch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]
2026-01-02 Set temperature unit correctly at boot when C
    [tft.cpp]
2026-03-11 Updated some default values, fixed wifi management and scanning. Fixed a bug with touchscreen not working sometimes.
    [sensors.cpp, tft.cpp]
2026-07-31 v0.8.3: Fix compiler warnings. Cleaned up sdcard. Initial attempt to track fan runtime
    [stream.cpp]

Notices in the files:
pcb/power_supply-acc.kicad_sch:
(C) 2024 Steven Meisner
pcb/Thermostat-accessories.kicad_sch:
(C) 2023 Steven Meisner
